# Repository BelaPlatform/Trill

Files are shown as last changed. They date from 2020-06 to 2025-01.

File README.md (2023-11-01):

# Trill: Touch Sensing for Makers

Trill sensors are designed to bring beautiful touch interaction to digital projects. Trill sensors are available now on the [Bela Shop](https://shop.bela.io/collections/trill) and via [Mouser Electronics](https://www.mouser.com/c/sensors/sensor-development-tools/?m=Bela).

## Trill libraries and examples

The Bela IDE comes pre-loaded with the [Trill library](https://github.com/BelaPlatform/Bela/tree/master/libraries/Trill) and [Trill examples](https://github.com/BelaPlatform/Bela/tree/master/examples/Trill).

For other platforms:

- [`Trill-Linux`](https://github.com/BelaPlatform/Trill-Linux) contains the Trill library and examples for Linux systems, such as Raspberry Pi

- [`Trill-Arduino`](https://github.com/BelaPlatform/Trill-Arduino) contains the Trill library and examples for Arduino, as well as Arduino-compatible systems such as Teensy. These also include examples of how to connect your Trill sensor to Processing to generate visuals.

## Trill hardware designs

This repo contains the editable PCB designs and manufacturing files for Trill sensors. You can download these schematic source and PCB design files and edit them yourself using [KiCad](https://www.kicad.org/).

### Source Files and Licenses

Trill hardware designs and this datasheet are available under a [Creative Commons Attribution-ShareAlike 4.0 International (CC BY-SA 4.0)](http://creativecommons.org/licenses/by-sa/4.0/) License, meaning they can be freely reused and remixed with attribution, provided modifications remain open source. Trill firmware is licensed under [GNU General Public License 3](https://www.gnu.org/licenses/gpl-3.0.html), meaning that you can freely use, remix, change and extend the code, but you are obligated to make the modified source code available alongside any binaries (flashed, or as files) that you release.

### Commercial Licensing

It's possible to use Trill design files and firmware for a commercial projects free of charge under [CC-BY-SA](http://creativecommons.org/licenses/by-sa/4.0/) (hardware) and [GPL](https://www.gnu.org/licenses/gpl-3.0.en.html) (firmware). Both licenses allow you to use these assets yourself under the license requirements, which include publicly releasing any changes you make to the designs under the same license.

If you want to use Trill design files but not provide attribution and/or not release your source code – for example, because you want to create something to sell using these files but don't want to make your source files public – this is still possible, but requires a commercial license. Augmented Instruments Ltd. can provide you with a commercial license that fits your project and its scope. Get in touch at info@bela.io to discuss your product and the license that's right for you. More information may be found at https://learn.bela.io/products/products-overview/open-source-licenses/#using-trill-in-commercial-products

Please note: The above commercial licensing applies only to modifications to our provided firmware code and PCB designs. You can buy Trill sensors and use them in any commercial or personal project without any additional licensing costs.

## Trill name and logo 

Trill and Bela names and logos are copyright Augmented Instruments Ltd. Any  designs that you release or produce should **not** use the Trill name or logo and/or the Bela name and logo, whether modified or exact copies.

## Datasheet

This repo contains the Trill datasheet. There is one datasheet for all Trill sensors that includes technical diagrams and usage information. 

## Fritzing files

Fritzing parts are available for all Trill sensors, in the [Bela Fritzing repo](https://github.com/belaplatform/fritzing).

## Learn more

The Bela Knowledge Base contains great documentation on using Trill! Visit [learn.bela.io/trill](https://learn.bela.io/trill) for more information, as well as our Get Started Guide.

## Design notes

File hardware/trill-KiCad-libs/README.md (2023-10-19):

# TRILL KiCad Library

This repo contains shared symbols, footprints and 3D files for TRILL projects.
Add the path to your symbols, footprints and 3d directory

## Installation

If all files of the repository are kept in place, the KiCad projects should contain the relative paths to the libraries and should find them without configuration. Please don't move folders!

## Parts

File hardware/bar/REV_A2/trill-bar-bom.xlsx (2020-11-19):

Name | Quantity | Value | Package | Description | Mouser # | Digi-Key # | Datasheet / Notes
C1 | 1 | 0.1uF | “0402" | Capacitor ceramic 0402; standard bypass cap 5V+
C2 | 1 | 2.2nF | “0402" | Capacitor ceramic 0402; 5% | 81-GRM36X222J50
IC1 | 1 | CY8C20636A-24LTXI | 48-QFN, 7x7mm | IC Cypress SoC | 727-CY8C20636A24LTXI
J1 | 1 | Grove connector, vertical SMT | SMD | 4-pin 2mm vertical Grove connector (Seeed)
R1-R2 | 2 | 100 ohm | “0402" | Resistor 0603 (standard part)
R3-R4 | 2 | 47k ohm | “0402" | Resistor 0603 (standard part)
Total | 8

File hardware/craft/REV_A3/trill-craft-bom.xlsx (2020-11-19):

Name | Quantity | Value | Package | Description | Mouser # | Digi-Key # | Datasheet / Notes
C1 | 1 | 0.1uF | "0603" | Capacitor ceramic 0402; standard bypass cap 5V+
C2 | 1 | 2.2nF | "0603" | Capacitor ceramic 0402; 5% | 81-GRM36X222J50
IC1 | 1 | CY8C20636A-24LTXI | 48-QFN, 7x7mm | IC Cypress SoC | 727-CY8C20636A24LTXI
R1-R2 | 2 | 100 ohm | "0603" | Resistor 0603 (standard part)
R3-R4 | 2 | 47k ohm | "0603" | Resistor 0603 (standard part)
Total | 7

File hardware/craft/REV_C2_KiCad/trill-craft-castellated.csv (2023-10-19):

Source: | /home/mxa/Code/Bela/trill-private/hardware/craft/REV_C2_KiCad/trill-craft-castellated.kicad_sch
Date: | So 26 Feb 2023 22:26:50 CET
Tool: | Eeschema 6.0.10-86aedd382b~118~ubuntu22.10.1
Generator: | /usr/share/kicad/plugins/bom_csv_grouped_by_value.py
Component Count: | 8
Individual Components:
Item | Qty | Reference(s) | Value | LibPart | Footprint | Datasheet
 |  | C1 | 100nF | Device:C | Capacitor_SMD:C_0402_1005Metric | ~
 |  | C2 | 2n2 | Device:C | Capacitor_SMD:C_0402_1005Metric | ~
 |  | JP1 | Jumper_2x3_Open | TRILL:Jumper_2x3_Open | TRILL:SolderJumper-2x3_P1.3mm_Open_Pad1.0x1.5mm | ~
 |  | R1 | 100 | Device:R | Resistor_SMD:R_0402_1005Metric | ~
 |  | R2 | 100 | Device:R | Resistor_SMD:R_0402_1005Metric | ~
 |  | R3 | 47k | Device:R | Resistor_SMD:R_0402_1005Metric | ~
 |  | R4 | 47k | Device:R | Resistor_SMD:R_0402_1005Metric | ~
 |  | U1 | CY8C206X6A | TRILL:CY8C206X6A | Package_DFN_QFN:QFN-48-1EP_6x6mm_P0.4mm_EP4.6x4.6mm | https://www.infineon.com/dgdl/Infineon-CY8C20XX6A_S_1.8_V_Programmable_CapSense_Controller_with_SmartSense_Auto-tuning_1-33_Buttons_0-6_Sliders-DataSheet-v26_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
Collated Components:
Item | Qty | Reference(s) | Value | LibPart | Footprint | Datasheet
1 | 1 | C1 | 100nF | Device:C | Capacitor_SMD:C_0402_1005Metric | ~
2 | 1 | C2 | 2n2 | Device:C | Capacitor_SMD:C_0402_1005Metric | ~
3 | 1 | JP1 | Jumper_2x3_Open | TRILL:Jumper_2x3_Open | TRILL:SolderJumper-2x3_P1.3mm_Open_Pad1.0x1.5mm | ~
4 | 2 | R1, R2 | 100 | Device:R | Resistor_SMD:R_0402_1005Metric | ~
5 | 2 | R3, R4 | 47k | Device:R | Resistor_SMD:R_0402_1005Metric | ~
6 | 1 | U1 | CY8C206X6A | TRILL:CY8C206X6A | Package_DFN_QFN:QFN-48-1EP_6x6mm_P0.4mm_EP4.6x4.6mm | https://www.infineon.com/dgdl/Infineon-CY8C20XX6A_S_1.8_V_Programmable_CapSense_Controller_with_SmartSense_Auto-tuning_1-33_Buttons_0-6_Sliders-DataSheet-v26_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

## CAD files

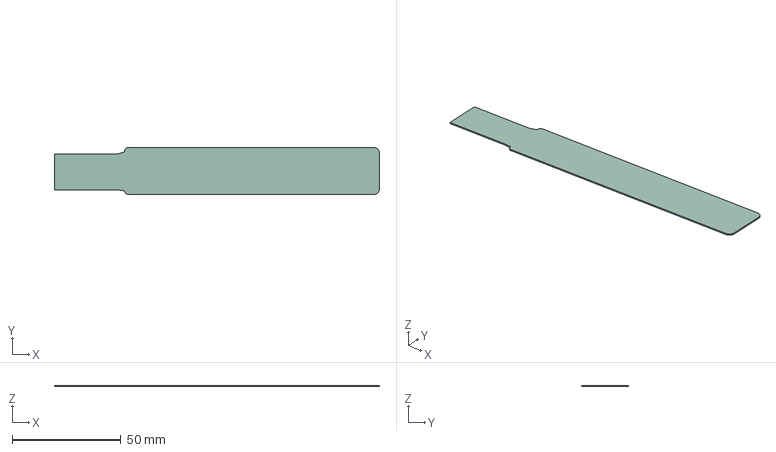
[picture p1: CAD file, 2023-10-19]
hardware/flex/trill-flex-slider/REV-C1-KiCad/trill-flex-slider.step
149.6 x 21.6 x 0.55 mm

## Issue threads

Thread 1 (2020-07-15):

Trill Square Firmware flashing question

jwktje, 2020-07-15:
Thanks very much first of all for open-sourcing all design files and code.
For a hobby project I'm trying to study the schematics and code to learn from it because I'm trying to build a prototype with capacitive touch.

I've already ordered a Trill Square to test with.
I was wondering however. If I was to integrate a design into my full PCB that integrates the CY8C20636A, how would I flash that IC?

The datasheet seems to mention something about the  CY3217-MiniProg1. Is that what I use to flash the sensor firmware or could I use something like an FTDI?

giuliomoro, 2020-07-23:
> The datasheet seems to mention something about the CY3217-MiniProg1.

The PSoC programmer that comes with it is one thing you could use.

You can also write your own embedded firmware and create a programming device yourself, and they provide a basic C library to do that. See these documents by Cypress for further details:
- "Host Sourced Serial Programming for CY8C20xx6A, CY8C20xx6AS, CY8C20xx6L, CY8C20xx7, CY8C20045
- CY8C20055" (AN59389) and "ISSP Programming Specification" (Document #: 001-57631)

fenicento, 2020-12-01:
I know it's not the best place to ask but I couldn't reach you personally, so feel free to remove this post: do you by any chance use HSSP with an Arduino, Teensy, or any other maker-friendly board? If so, would you mind sharing it? I'm having a hard time finding a programmer for CY8C20636A and can't really manage to write a firmware for a custom programmer.

Thanks

giuliomoro, 2020-12-02:
you don't need to write a programmer from scratch. The second resource mentioned above includes a zip archive with a C implementation of the protocol. I am not sure what platform it is for, but you can port it to your platform of choice by replacing the functions in `issp_driver_routines.c` so that they work on your platform.

Alternatively, some PSoC programmers seem to still be around there [somewhere](https://www.aliexpress.com/item/32381156184.html).

Closed 2020-12-02.

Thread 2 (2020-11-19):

Trill Craft R and C values

fenicento, 2020-11-19:
It is not specified what use and values the resistors and capacitors on boards have. I'll try to make a guess for the ones in the Trill Craft, but it would be nice to integrate these info in the repo.

R1 and R2: I2C pull-up resistors, 4.7kΩ
R3 and R4: I2C address pin pull down resistor, 4.7kΩ
C1: decoupling capacitor, 0.1µF
C2: Cmod capacitor for Cypress CSA sensing method ([described here](http://dlm.cypress.com.edgesuite.net/akdlm/old/design_resources/developer_kits/contents/cy3280_24x94_universal_capsense_controller_board_16.pdf)), 1nF

are these values correct?

giuliomoro, 2020-11-19:
sorry BOMs were missing. They are there now

Closed 2020-11-19.

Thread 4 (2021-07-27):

Trill square not completely flat

wjslager, 2021-07-27:
I have a trill square here that is not 100% flat. Not really a big issue but if one would want to mount it flush in a surface the edges could stand out.

https://user-images.githubusercontent.com/3001621/127160647-299aba64-3ae9-411e-b594-94e6d92a7a33.mp4

I think this can be fixed by having equal amounts of copper on each layer, it seems like the backside of the PCB has only traces and no plane.

apmcpherson, 2021-07-28:
This is a good point, but maybe not an easy fix: adding solid copper to the back could increase baseline capacitance of the sensors and ultimately lower the sensitivity of the readings. We will keep an eye on the assembly process to see what we can do to keep them as flat as possible. Since the boards are relatively thin and partly flexible, they could perhaps be secured to a rigid backplane using adhesive.

mxa, 2023-10-24:
Closing, since this is a  issue inherent of the properties of the PCB, (thin, large, 4-layer), can't be solved by designing it differently while keeping the same properties.

mxa, 2023-10-24:
Closing, since this is a  issue inherent of the properties of the PCB, (thin, large, 4-layer), can't be solved by designing it differently while keeping the same properties.

mxa, 2023-10-24:
Closing, since this is a  issue inherent of the properties of the PCB, (thin, large, 4-layer), can't be solved by designing it differently while keeping the same properties.

mxa, 2023-10-24:
Closing, since this is a  issue inherent of the properties of the PCB, (thin, large, 4-layer), can't be solved by designing it differently while keeping the same properties.

Closed 2023-10-24.

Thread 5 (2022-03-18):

Request: Trill Craft (as a component) KiCAD library

DocSunset, 2022-03-18:
It would be fantastic to have KiCAD symbols and footprints for integrating Trill Craft into schematics and PCBs, similar to the library files available for the other Trill devices.

mxa, 2023-10-26:
Say hi to a craft symbol, footprint and 3d model to use in your projects.

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

mxa, 2023-10-28:
The footprint still needs to be verified in the physical world, feedback welcome, especially on the size and shape of the smd pads.

Closed 2023-10-26.

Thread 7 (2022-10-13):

Spurious touches reported

stonehippo, 2022-10-13:
I've come across an issue with a couple my Trill boards (specifically a Bar and a Square, both acquired during the Kickstarter campaign). The sensors will report a touch that is not there after it has been running for a while. For example, on my Square, I am getting a horizontal touch at centroid location 1280. This seems to be consistent, and happens with both the Trill-Arduino firmware and a driver that I've written for CircuitPython.

I haven't looked at the firmware yet, but I'm going to take a read through to see how centroids are calculated. However, because this issue seems to appear on the sensor between different software implementations on different microcontrollers, I have to this it's the sensor itself having issues.

Is this something others have seen?

giuliomoro, 2022-10-14:
Things that can cause ghost touches are moisture (e.g.: a thin layer of water on the surface or edge of the sensor) or something changing with the surroundings of the sensor. Is it resting on a flat surface, taped or glued down, or is it in a precarious position balancing on the cable sticking out of the back? Also remember that a sensor calibration is done automatically when the sensor is initialised by the sofware, so for instance if you have one finger on the sensor while the program starts and then you remove it you may have unexpected readings: you are not supposed to touch the sensor when the program starts.

stonehippo, 2022-10-15:
It's definitely not a touch during calls to updateBaseline. I've got the Square mounted in the 3D printed base, but it was happening beforehand, so I suspect it might be something on the sensor. In the case of the Bar, I think it was maybe a spec of dust on the pins of the chip; removing it may have resolved the issue on that sensor.

I do note that resetting the chip fixes the issue for a while (presumably because of the baseline update) but then it comes back, especially after a multiple touch. I'm going to dump the baseline for a while and see if I can map what's happening.

I've ordered a few more Trills for a project, and my CircuitPython library is almost complete, so I'll be spending plenty of time with them.

giuliomoro, 2022-10-15:
Good that it got fixed on the BAR. For the SQUARE, it would be helpful to look at the RAW pad readings when the ghost touch happens.

mxa, 2023-10-24:
A good place to continue this conversation is the Bela forum https://forum.bela.io/t/trill
Please share screenshots of the baseline readings.

Closed 2023-10-24.

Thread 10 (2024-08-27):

Table 12 in the datasheet appears to be incorrect

george-norton, 2024-08-27:
I have a Trill Hex rev C2 and I believe the centroid data report structure is different from the datasheet. The datasheet includes this table:
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
But I believe my sensor is actually reporting:
```
uint16_t vertical_location[4];
uint16_t vertical_size[4];
uint16_t horizontal_location[4];
uint16_t horizontal_size[4];
```

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
george-norton, 2024-08-27:
Hello, sorry - I am not sure what is in that zip file, is it new firmware?

FYI, I am running a Linux system and have started work on a QMK (mechanical keyboard firmware) driver for the Hex trackpad, I have not installed or run any of the Bela development tools.

giuliomoro, 2024-08-27:
Nope that was spam

GoldenCaterpie, 2024-08-27:
> Hello, sorry - I am not sure what is in that zip file, is it new firmware?
>
> FYI, I am running a Linux system and have started work on a QMK (mechanical keyboard firmware) driver for the Hex trackpad, I have not installed or run any of the Bela development tools.

SRRY, THAT'S A VIRUS AND MY ACCOUNT HAS BEEN HIJACKED BY IT :(

giuliomoro, 2024-08-27:
> But I believe my sensor is actually reporting:

 You are right. Keep in mind those uint16_t are big endian so if you are trying to map a `struct` to that it may or may not work depending on your architecture.

george-norton, 2024-08-27:
Yes, I am handling the byte swapping. I have a proof of concept functional driver.

giuliomoro, 2024-08-27:
Great, you can also look at the [arduino](https://github.com/BelaPlatform/Trill-Arduino) and [linux](https://github.com/BelaPlatform/Trill-Linux) libraries for any further doubts

george-norton, 2024-08-27:
This ticket is probably the wrong place, so please let me know if you want to move elsewhere. But the documentation states that the 2D sensors only support "pseudo multitouch" without providing any real details. I am imagining that the axes are being treated independently and it becomes difficult to track which x and y report are a pair? I can work with a single touch + contact count for emulating a mouse, but I am also working on some USB HID digitiser stuff with Azoteq and MaxTouch sensors. It would be great if I could somehow reliably track 2 or 3 fingers.

giuliomoro, 2024-08-27:
The correct memory map has
touch N location at offset 4 + N:N+1
touch N size at offset 4 + 2*numTouches + N:N+1
for 2-axis:
horizontal touch N location at offset 4 + 4*numTouches + N:N+1
horizontal touch N size at offset 4 + 6*numTouches + N:N+1

numTouches = 5 for 1-axis and
numTouches = 4 for 2-axis

Not sure how to best represent this in a a table.

giuliomoro, 2024-10-31:
Should look something like this I think
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

giuliomoro, 2024-10-31:
@clwe can you double check this diagram https://github.com/BelaPlatform/Trill/issues/10#issuecomment-2449711737 to make sure I didn't do anything wrong before Max translates it into Latex?

clwe, 2024-10-31:
OMG indexing hell!
You guessed it - there is a small error. The initial offset (4) to the formulas for indexing into the offsets was missing.
Maybe we could make it more explicit and show the array layout for the two variants as below?
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
The mapping with indexing formulas had a slight error as well. Lets take a small `n` for the running index and the big `N` for the maximum number of touches per device.

`N = 5` for 1-axis devices
`N = 4` for 2-axis devices

If touch number `n`  is `[0 ... N-1]` then the offsets for the fields corresponding to touch `n` in the array are:

`location = 4 + 2*n:2*n+1`
`size = 4 + 2*N + 2*n:2*n+1`
`horizontal location = 4 + 4*N + 2*n:2*n+1` (2-axis only)
`horizontal size = 4 + 6*N + 2*n:2*n+1` (2-axis only)

clwe, 2024-10-31:
@mxa here is a .csv:
[trill datasheet array mapping.csv](https://github.com/user-attachments/files/17590456/trill.datasheet.array.mapping.csv)

giuliomoro, 2024-10-31:
> The initial offset (4) to the formulas for indexing into the offsets was missing.

right, missing the 4 + then?

> Maybe we could make it more explicit and show the array layout for the two variants as below?

Maybe ... or maybe showing the formula makes it easier to translate into code?

mxa, 2024-11-01:
Revised table:

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

What should be changed in the text?

giuliomoro, 2024-11-01:
Editing needs to encompass the paragraph that starts at the beginning of 7.7.1:

The data in the Payload region represents the touch location and size for each of the touches that the device can detect. The location and size of each touch are each represented by a 2-byte word. Each word represents a 16-bit unsigned integer in Big Endian format. Touch location and size values are stored in a buffer of contiguous memory, starting from the beginning of the Payload region. For each sensing axis, location data for all touches is presented first, followed by size data. Devices with two axes of sensing (Trill Square, Trill Hex) store vertical touches first, followed by horizontal touches. The readings of the two exposed pads on Trill Ring are stored after the touch values as a 16-bit unsigned integers in Big Endian format.
The memory offset for the start of the location data for a given touch n on a given sensing axis is p + 2n; the memory offset for the start of the size data for a given touch n is p + 2N + 2n, where N is the total number of touches on the sensing axis. The offset p is 4 (the beginning of the Payload region) for 1-axis devices or for the first axis of sensing of 2-axis devices, while it is 4 + 2N for the second axis of sensing of 2-axis devices. Tables 12 and 13 detail the memory map of the Payload region for 1-axis and 2-axis devices, respectively.
The size of valid data (in bytes) in the Payload memory region for a sensor which provides a total of N touches across its axes and E extra pads is M = 4N + 2E. The host processor should read M bytes starting at offset 4 to retrieve the full touch data. The number of available touches and the corresponding data size for each sensor type in Centroid mode is shown in Table 14 . <<<< correct number?

giuliomoro, 2024-11-01:
^^^ worth reviewing that what I wrote matches the corrected diagrams :-)

giuliomoro, 2024-11-01:
also I think the captions should say `when _a_ {1,2}-axis sensor` (i.e.: add the "a")

giuliomoro, 2024-11-01:
Could be yes. Also, don't use "Horz", use "horizontal" or "horiz" if you need to abbreviate

clwe, 2024-11-01:
No need to parametrize a start point. It's taken into account. For example, to get the first horizontal touch position, you choose N=4 and n=0. So the offset is '4 + 4*4+ 0:1 = 20:21'.

Closed 2024-11-01.

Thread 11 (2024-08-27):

explain pseudo-multitouch in the datasheet

giuliomoro, 2024-08-27:
@george-norton write

> documentation states that the 2D sensors only support "pseudo multitouch" without providing any real details. I am imagining that the axes are being treated independently and it becomes difficult to track which x and y report are a pair? I can work with a single touch + contact count for emulating a mouse, but I am also working on some USB HID digitiser stuff with Azoteq and MaxTouch sensors. It would be great if I could somehow reliably track 2 or 3 fingers.

What we mean by pseudo-multitouch here is that there are 15 capacitive channels on each axis. What you get is a list of the touches on the horizontal axis and a list of touches on the vertical axis. If you have two touches, you will not know which vertical touch corresponds to which horizontal touch. Also, if you have multiple touches aligned on the same vertical axis they will look like a single touch on the horizontal axis.

Worth adding this to the datasheet

mxa, 2024-11-01:
Proposed new table footnote 1, getting rid of the term "pseudo-multi-touch" entirely:

Trill 2-axis pads (Trill Square and Trill Hex) are not multi-touch sensors. While they are able to detect that more than one finger is touching the pad, they are unable to determine the exact locations of the touch points unambiguously.
This is because these X/Y sensors feature a square matrix configuration of pads, with the 30 channels of capacitive sensing distributed between two axes (15 channels per axis). A single touch results in the return of one pair of X/Y coordinates, which are accurate. However, with multiple touches present, Trill will register all touches and return them as two lists, one list for touches on the X axis and the other list for touches on the Y axis. Unfortunately, there is no way to accurately pair these X and Y values to produce accurate touch locations.

Closed 2024-11-01.

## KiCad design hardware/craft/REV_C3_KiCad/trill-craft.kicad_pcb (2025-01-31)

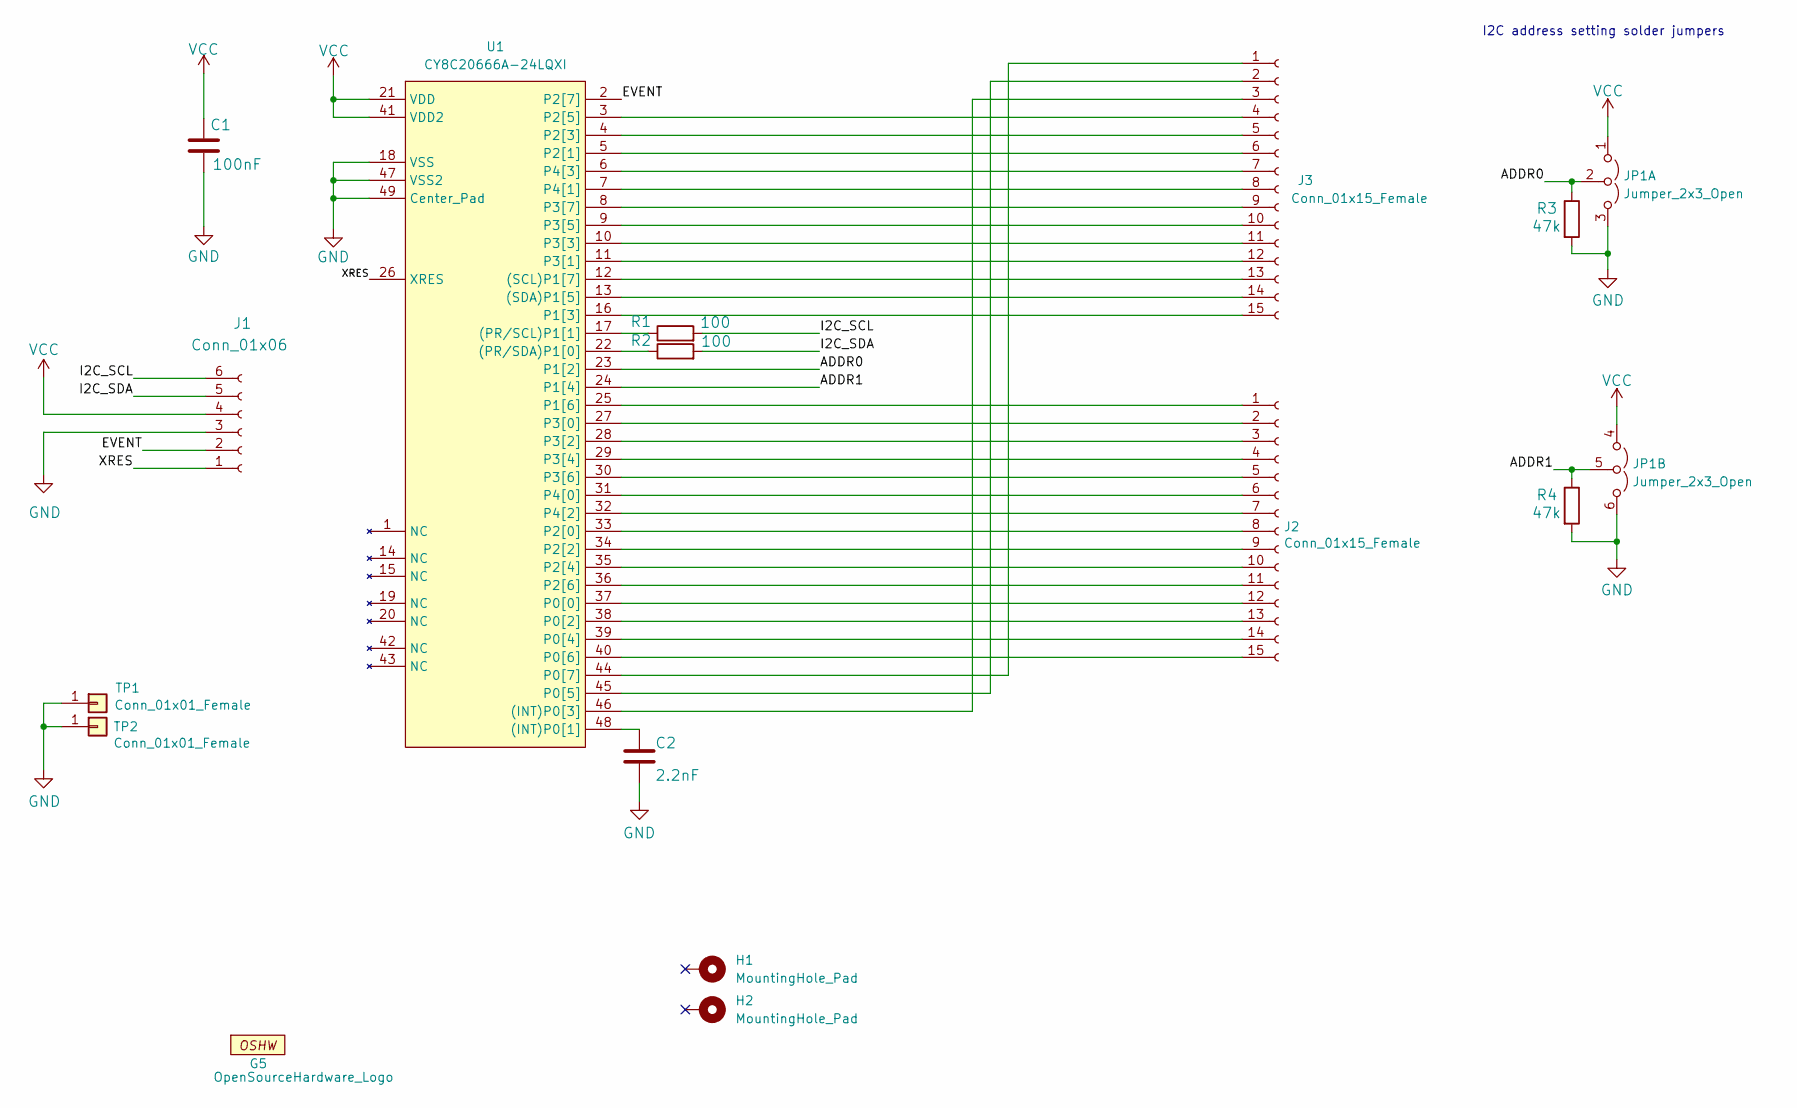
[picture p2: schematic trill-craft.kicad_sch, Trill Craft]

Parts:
C1: 100nF; C_0402_1005Metric
C2: 2.2nF; C_0402_1005Metric
G5: OpenSourceHardware_Logo
H1, H2: MountingHole_Pad; MountingHole_3.2mm_M3_ISO14580_Pad
J1: Conn_01x06; trill_craft_1X6_2.54mm_castelated_round
J2, J3: Conn_01x15_Female; trill_craft_1x15_2.54mm_castellated_round
JP1: Jumper_2x3_Open; SolderJumper-2x3_P1.3mm_Open_Pad1.0x1.5mm
R1, R2: 100; R_0402_1005Metric
R3, R4: 47k; R_0402_1005Metric
TP1, TP2: Conn_01x01_Female; trill_craft_circular_pad_smd
U1: CY8C20666A-24LQXI; QFN-48-1EP_6x6mm_P0.4mm_EP4.6x4.6mm

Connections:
/ADDR0: JP1.2 (C), R3.1, U1.23 (P1[2])
/ADDR1: JP1.5 (A), R4.1, U1.24 (P1[4])
/EVENT: J1.2, U1.2 (P2[7])
/I2C_SCL: J1.6, R1.2
/I2C_SDA: J1.5, R2.2
/XRES: J1.1, U1.26 (XRES)
GND: C1.1, C2.2, J1.3, JP1.3 (B), JP1.6 (B), R3.2, R4.2, TP1.1, TP2.1, U1.18 (VSS), U1.47 (VSS2), U1.49 (Center_Pad)
unnamed: J2.1, U1.25 (P1[6])
unnamed: J2.2, U1.27 (P3[0])
unnamed: J2.3, U1.28 (P3[2])
unnamed: J2.4, U1.29 (P3[4])
unnamed: J2.5, U1.30 (P3[6])
unnamed: J2.6, U1.31 (P4[0])
unnamed: J2.7, U1.32 (P4[2])
unnamed: J2.8, U1.33 (P2[0])
unnamed: J2.9, U1.34 (P2[2])
unnamed: J2.10, U1.35 (P2[4])
unnamed: J2.11, U1.36 (P2[6])
unnamed: J2.12, U1.37 (P0[0])
unnamed: J2.13, U1.38 (P0[2])
unnamed: J2.14, U1.39 (P0[4])
unnamed: J2.15, U1.40 (P0[6])
unnamed: J3.1, U1.44 (P0[7])
unnamed: J3.2, U1.45 (P0[5])
unnamed: J3.3, U1.46 ((INT)P0[3])
unnamed: J3.4, U1.3 (P2[5])
unnamed: J3.5, U1.4 (P2[3])
unnamed: J3.6, U1.5 (P2[1])
unnamed: J3.7, U1.6 (P4[3])
unnamed: J3.8, U1.7 (P4[1])
unnamed: J3.9, U1.8 (P3[7])
unnamed: J3.10, U1.9 (P3[5])
unnamed: J3.11, U1.10 (P3[3])
unnamed: J3.12, U1.11 (P3[1])
unnamed: J3.13, U1.12 ((SCL)P1[7])
unnamed: J3.14, U1.13 ((SDA)P1[5])
unnamed: J3.15, U1.16 (P1[3])
unnamed: C2.1, U1.48 ((INT)P0[1])
unnamed: R1.1, U1.17 ((PR/SCL)P1[1])
unnamed: R2.1, U1.22 ((PR/SDA)P1[0])
VCC: C1.2, J1.4, JP1.1 (A), JP1.4 (A), U1.21 (VDD), U1.41 (VDD2)

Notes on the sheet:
I2C address setting solder jumpers

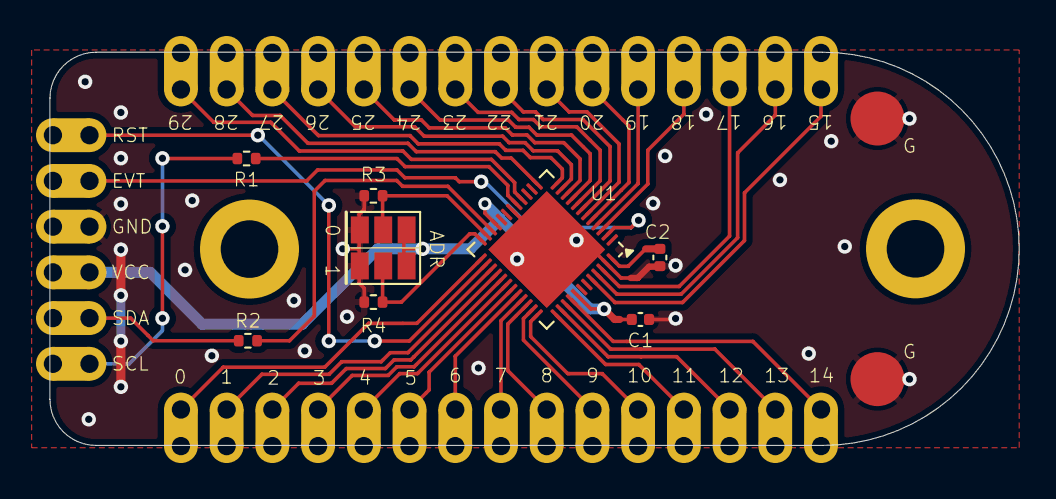
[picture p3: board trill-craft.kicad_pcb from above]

Board: 2 copper layers, 53.8 x 21.8 mm, 16 parts (1 on the bottom side), 41 nets.

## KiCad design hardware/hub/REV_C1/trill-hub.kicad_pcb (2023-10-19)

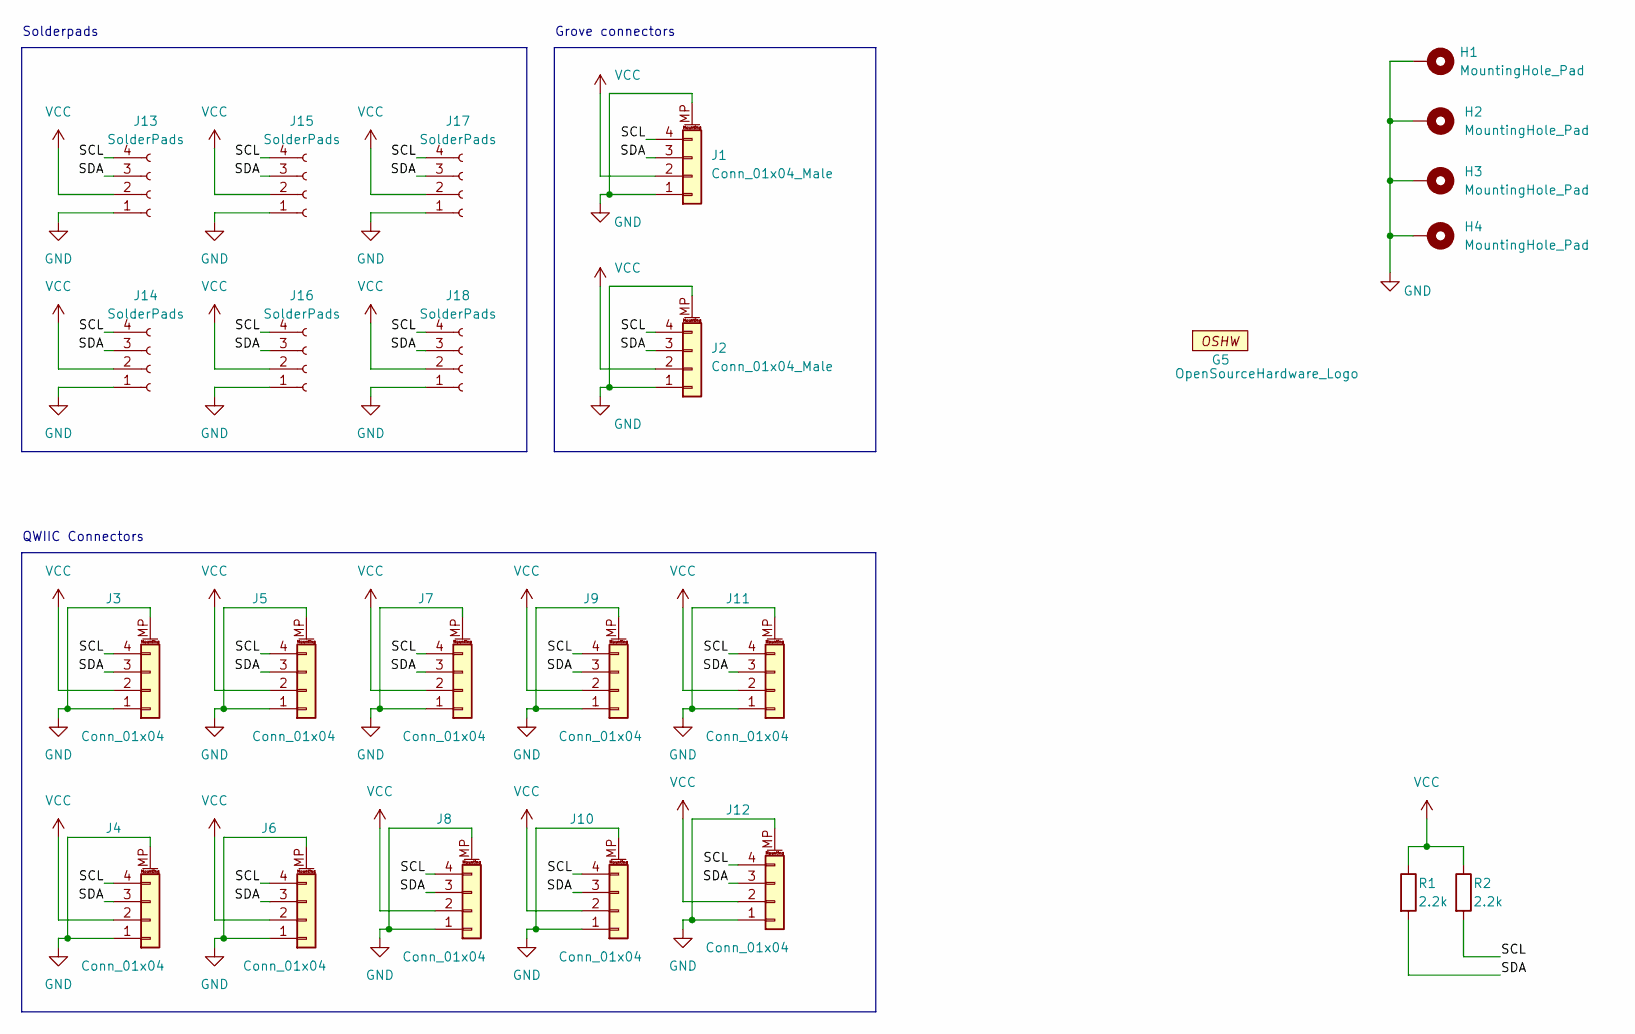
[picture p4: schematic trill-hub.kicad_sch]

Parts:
G5: OpenSourceHardware_Logo
H1, H2, H3, H4: MountingHole_Pad; MountingHole_3.2mm_M3_ISO14580_Pad
J1, J2: Conn_01x04_Male; JST_PH_B4B-PH-SM4-TB_1x04-1MP_P2.00mm_Vertical
J3, J4, J5, J6, J7, J8, J9, J10, J11, J12: Conn_01x04; qwiic_vertical_SMD
J13, J14, J15, J16, J17, J18: SolderPads; Connector_1x04_LongPads
R1, R2: 2.2k; R_0402_1005Metric

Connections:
/SCL: J1.4, J2.4, J3.4, J4.4, J5.4, J6.4, J7.4, J8.4, J9.4, J10.4, J11.4, J12.4, J13.4, J14.4, J15.4, J16.4, J17.4, J18.4, R2.2
/SDA: J1.3, J2.3, J3.3, J4.3, J5.3, J6.3, J7.3, J8.3, J9.3, J10.3, J11.3, J12.3, J13.3, J14.3, J15.3, J16.3, J17.3, J18.3, R1.2
GND: H1.1, H2.1, H3.1, H4.1, J1.1, J1.MP (MountPin), J2.1, J2.MP (MountPin), J3.1, J3.MP (MountPin), J4.1, J4.MP (MountPin), J5.1, J5.MP (MountPin), J6.1, J6.MP (MountPin), J7.1, J7.MP (MountPin), J8.1, J8.MP (MountPin), J9.1, J9.MP (MountPin), J10.1, J10.MP (MountPin), J11.1, J11.MP (MountPin), J12.1, J12.MP (MountPin), J13.1, J14.1, J15.1, J16.1, J17.1, J18.1
VCC: J1.2, J2.2, J3.2, J4.2, J5.2, J6.2, J7.2, J8.2, J9.2, J10.2, J11.2, J12.2, J13.2, J14.2, J15.2, J16.2, J17.2, J18.2, R1.1, R2.1

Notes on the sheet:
Solderpads
QWIIC Connectors
Grove connectors

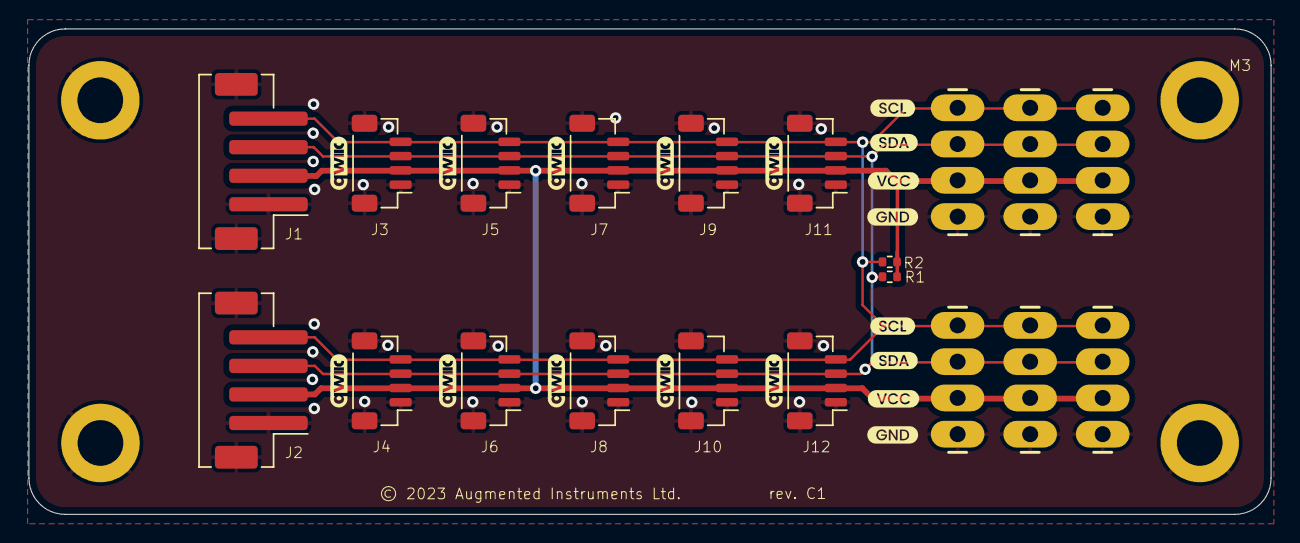
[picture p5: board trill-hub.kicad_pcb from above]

Board: 2 copper layers, 87.0 x 34.0 mm, 25 parts (1 on the bottom side), 4 nets.

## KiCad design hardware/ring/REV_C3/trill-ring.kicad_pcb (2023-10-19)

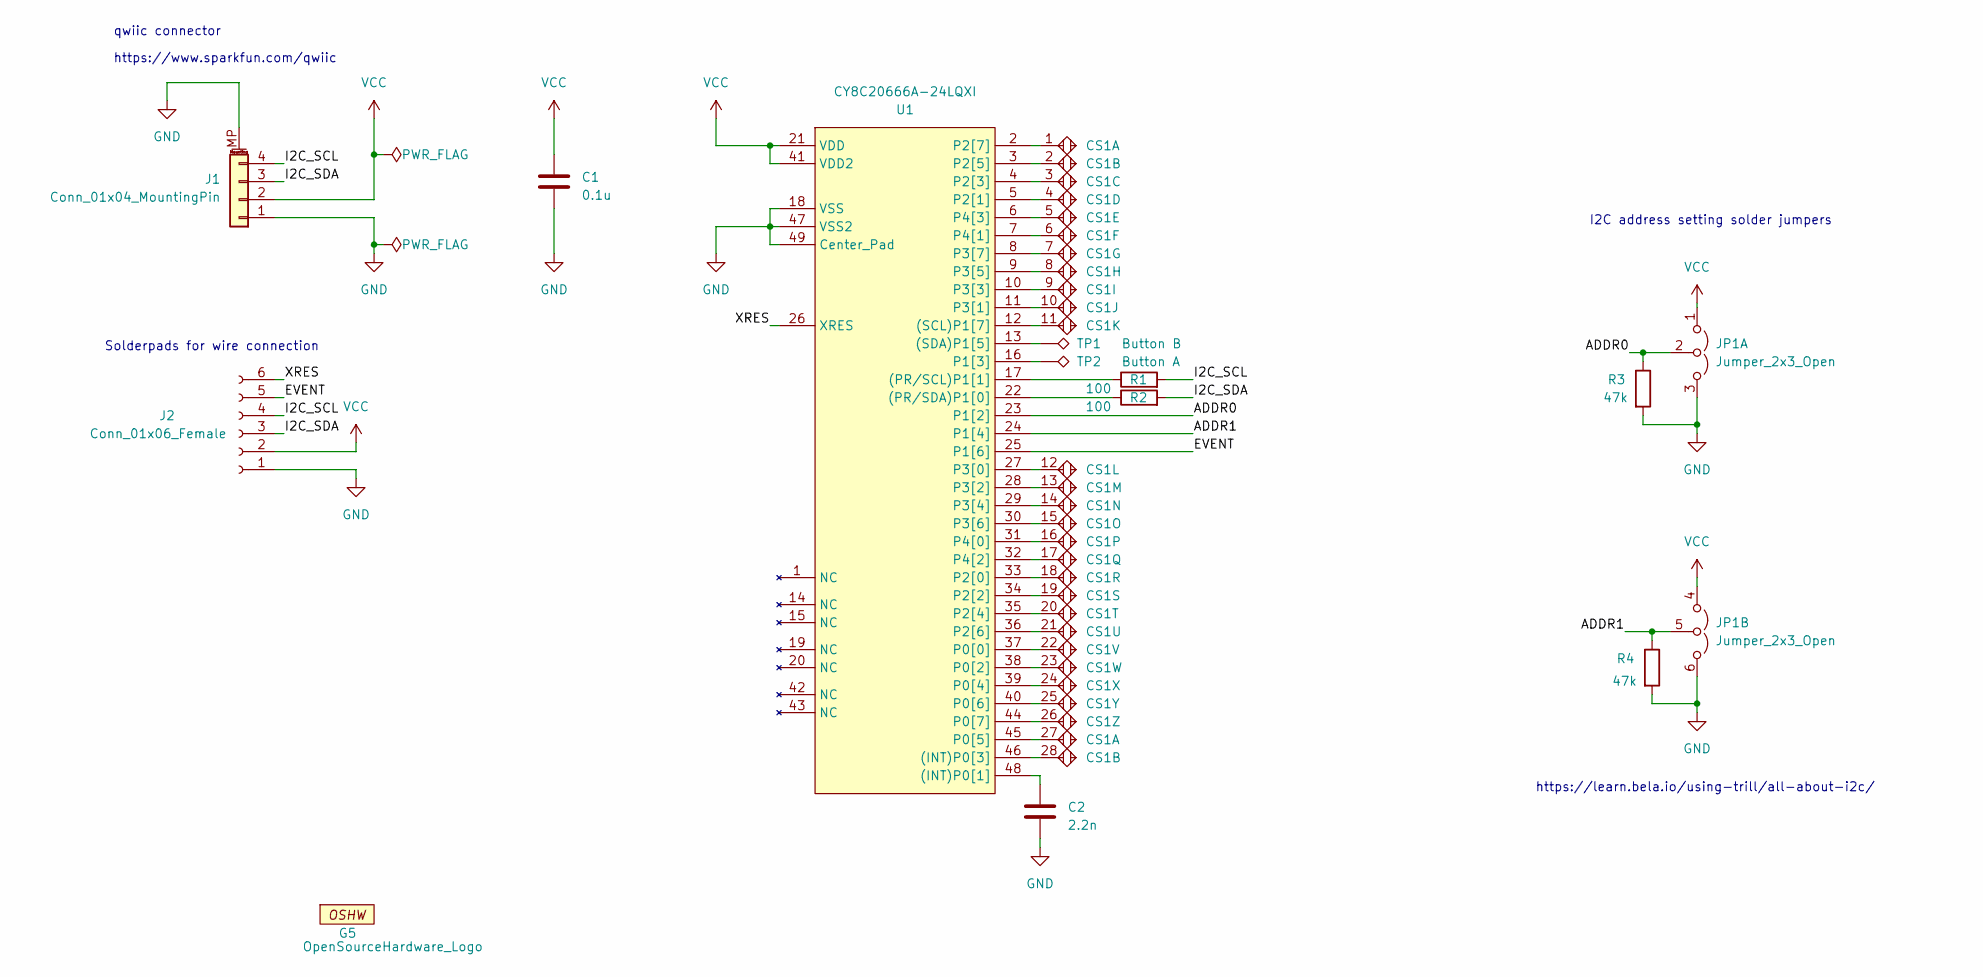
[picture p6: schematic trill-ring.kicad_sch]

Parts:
C1: 0.1u; C_0402_1005Metric
C2: 2.2n; C_0402_1005Metric
CS1: TRILL_RING-28_CapSense; TRILL_RING_CapSense
G5: OpenSourceHardware_Logo
J1: Conn_01x04_MountingPin; qwiic_horizontal_SMD
J2: Conn_01x06_Female; I2C+EVT_RST_Wire_connector_SMD
JP1: Jumper_2x3_Open; SolderJumper-2x3_P1.3mm_Open_Pad1.0x1.5mm
R1, R2: 100; R_0402_1005Metric
R3, R4: 47k; R_0402_1005Metric
TP1: Button B; TestPoint_Pad_D2.0mm
TP2: Button A; TestPoint_Pad_D2.0mm
U1: CY8C20666A-24LQXI; QFN-48-1EP_6x6mm_P0.4mm_EP4.6x4.6mm

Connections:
/ADDR0: JP1.2 (C), R3.1, U1.23 (P1[2])
/ADDR1: JP1.5 (A), R4.1, U1.24 (P1[4])
/EVENT: J2.5, U1.25 (P1[6])
/I2C_SCL: J1.4, J2.4, R1.2
/I2C_SDA: J1.3, J2.3, R2.2
/XRES: J2.6, U1.26 (XRES)
GND: C1.2, C2.2, J1.1, J1.MP (MountPin), J2.1, JP1.3 (B), JP1.6 (B), R3.2, R4.2, U1.18 (VSS), U1.47 (VSS2), U1.49 (Center_Pad)
unnamed: C2.1, U1.48 ((INT)P0[1])
unnamed: CS1.28, U1.46 ((INT)P0[3])
unnamed: R1.1, U1.17 ((PR/SCL)P1[1])
unnamed: R2.1, U1.22 ((PR/SDA)P1[0])
unnamed: CS1.11, U1.12 ((SCL)P1[7])
unnamed: TP1.1, U1.13 ((SDA)P1[5])
unnamed: CS1.22, U1.37 (P0[0])
unnamed: CS1.23, U1.38 (P0[2])
unnamed: CS1.24, U1.39 (P0[4])
unnamed: CS1.27, U1.45 (P0[5])
unnamed: CS1.25, U1.40 (P0[6])
unnamed: CS1.26, U1.44 (P0[7])
unnamed: TP2.1, U1.16 (P1[3])
unnamed: CS1.18, U1.33 (P2[0])
unnamed: CS1.4, U1.5 (P2[1])
unnamed: CS1.19, U1.34 (P2[2])
unnamed: CS1.3, U1.4 (P2[3])
unnamed: CS1.20, U1.35 (P2[4])
unnamed: CS1.2, U1.3 (P2[5])
unnamed: CS1.21, U1.36 (P2[6])
unnamed: CS1.1, U1.2 (P2[7])
unnamed: CS1.12, U1.27 (P3[0])
unnamed: CS1.10, U1.11 (P3[1])
unnamed: CS1.13, U1.28 (P3[2])
unnamed: CS1.9, U1.10 (P3[3])
unnamed: CS1.14, U1.29 (P3[4])
unnamed: CS1.8, U1.9 (P3[5])
unnamed: CS1.15, U1.30 (P3[6])
unnamed: CS1.7, U1.8 (P3[7])
unnamed: CS1.16, U1.31 (P4[0])
unnamed: CS1.6, U1.7 (P4[1])
unnamed: CS1.17, U1.32 (P4[2])
unnamed: CS1.5, U1.6 (P4[3])
VCC: C1.1, J1.2, J2.2, JP1.1 (A), JP1.4 (A), U1.21 (VDD), U1.41 (VDD2)

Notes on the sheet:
I2C address setting solder jumpers
qwiic connector
Solderpads for wire connection
https://learn.bela.io/using-trill/all-about-i2c/
https://www.sparkfun.com/qwiic

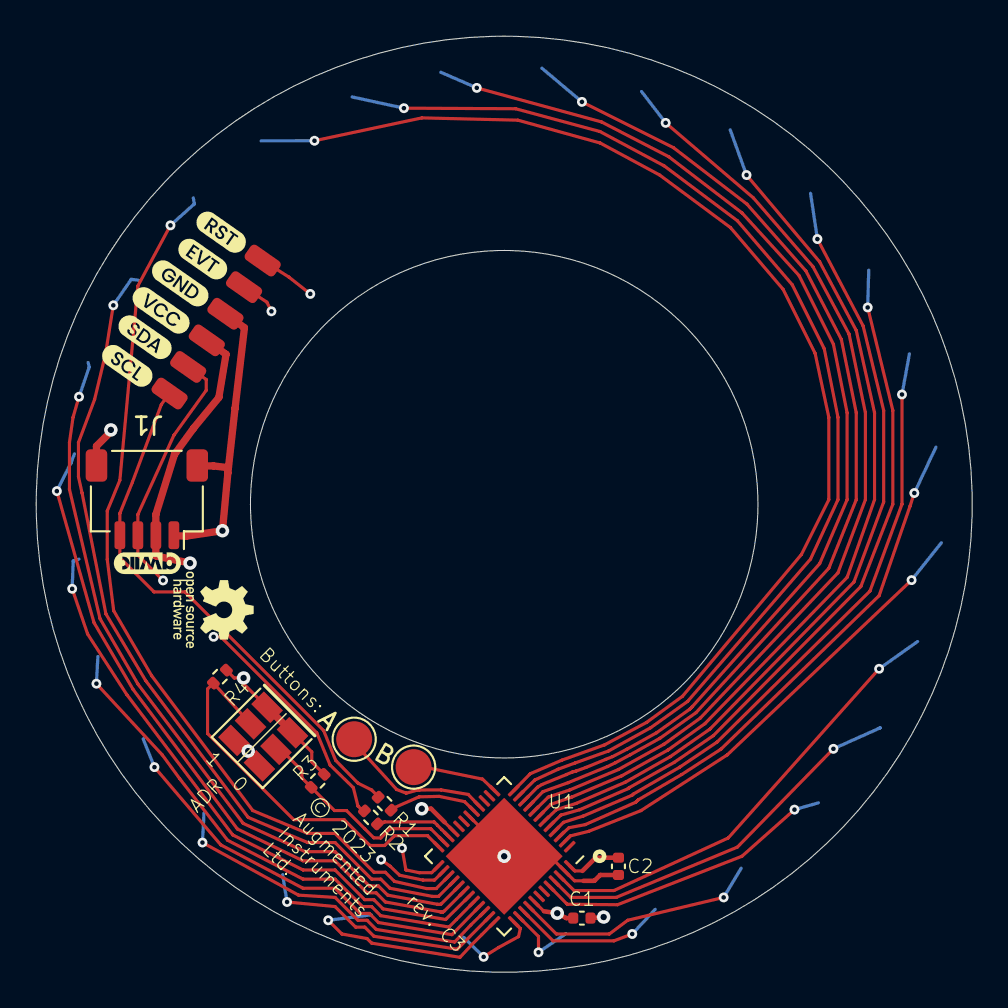
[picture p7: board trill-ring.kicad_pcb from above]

Board: 4 copper layers, 52.0 x 52.0 mm, 14 parts (0 on the bottom side), 41 nets.

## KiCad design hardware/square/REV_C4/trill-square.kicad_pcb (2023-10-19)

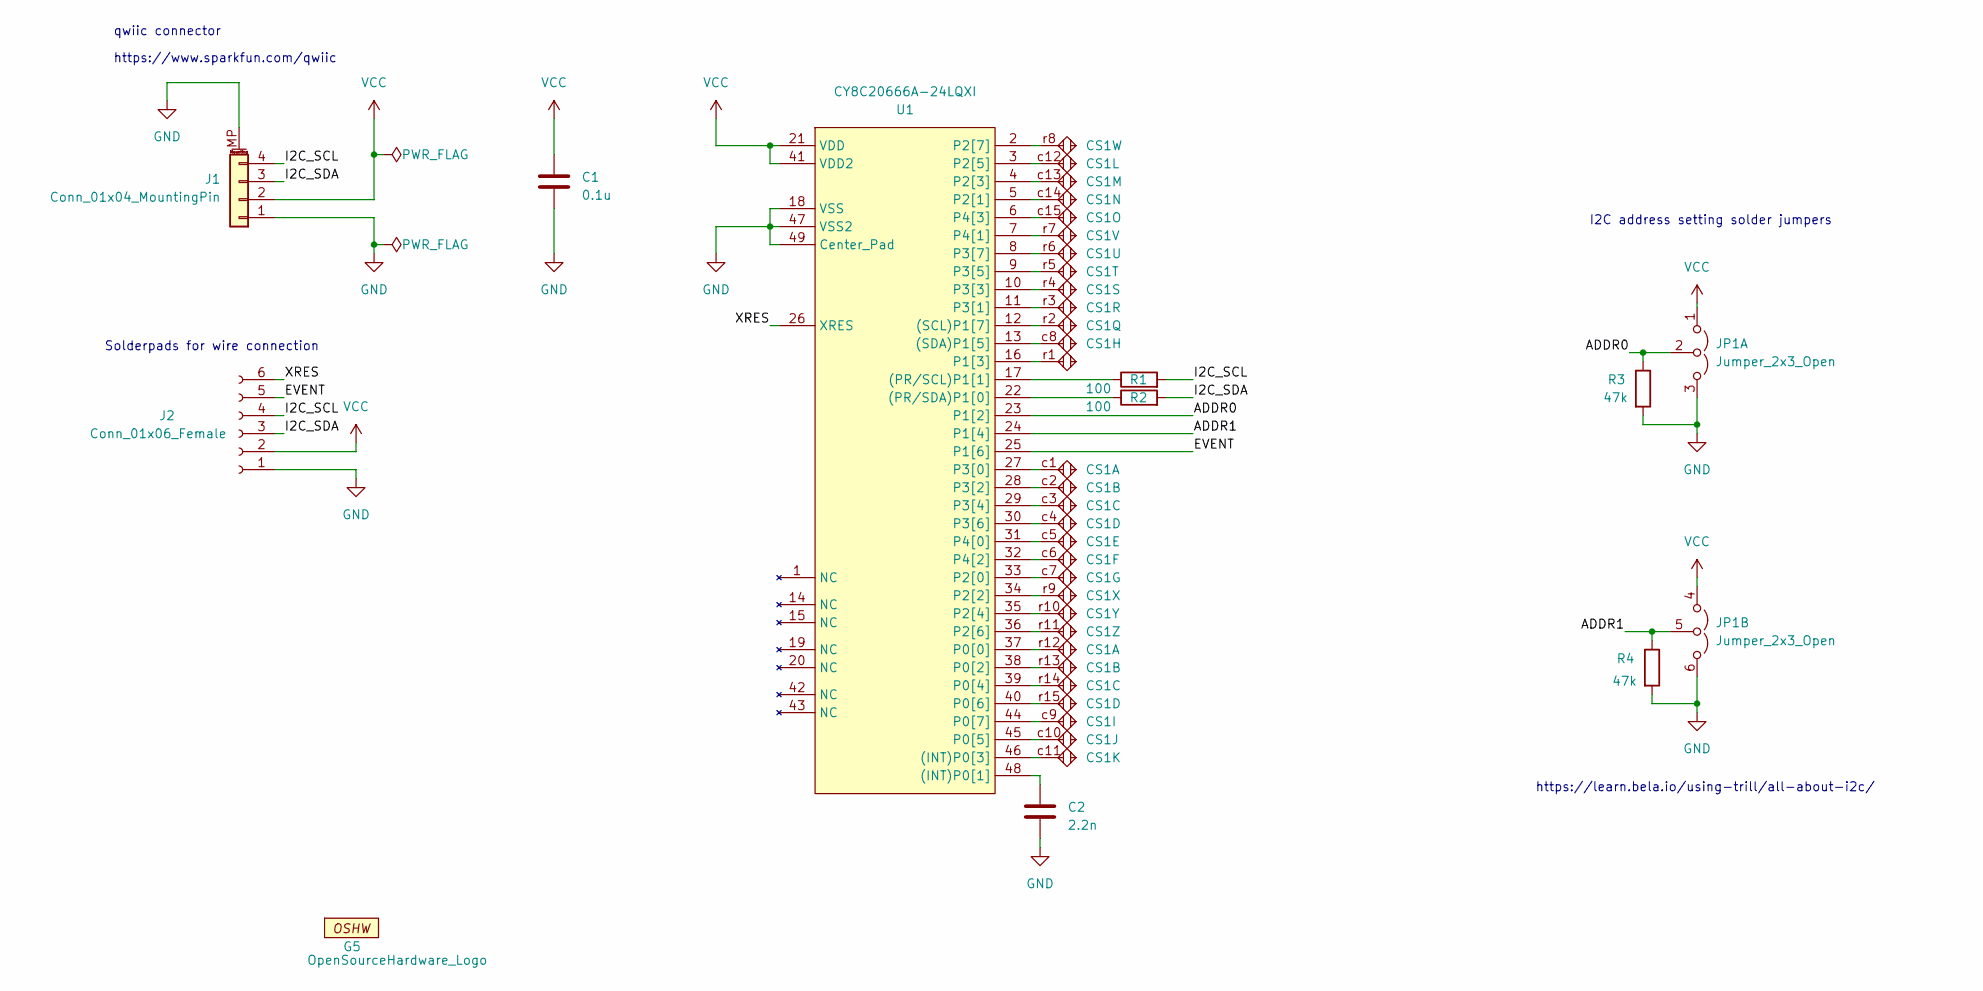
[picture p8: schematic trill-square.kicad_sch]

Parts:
C1: 0.1u; C_0402_1005Metric
C2: 2.2n; C_0402_1005Metric
CS1: CapSensePad; TRILL_SQUARE_CapSense
G5: OpenSourceHardware_Logo
J1: Conn_01x04_MountingPin; qwiic_horizontal_SMD
J2: Conn_01x06_Female; I2C+EVT_RST_Wire_connector_SMD
JP1: Jumper_2x3_Open; SolderJumper-2x3_P1.3mm_Open_Pad1.0x1.5mm
R1, R2: 100; R_0402_1005Metric
R3, R4: 47k; R_0402_1005Metric
U1: CY8C20666A-24LQXI; QFN-48-1EP_6x6mm_P0.4mm_EP4.6x4.6mm

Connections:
/ADDR0: JP1.2 (C), R3.1, U1.23 (P1[2])
/ADDR1: JP1.5 (A), R4.1, U1.24 (P1[4])
/EVENT: J2.5, U1.25 (P1[6])
/I2C_SCL: J1.4, J2.4, R1.2
/I2C_SDA: J1.3, J2.3, R2.2
/XRES: J2.6, U1.26 (XRES)
GND: C1.2, C2.2, J1.1, J1.MP (MountPin), J2.1, JP1.3 (B), JP1.6 (B), R3.2, R4.2, U1.18 (VSS), U1.47 (VSS2), U1.49 (Center_Pad)
unnamed: C2.1, U1.48 ((INT)P0[1])
unnamed: CS1.c11, U1.46 ((INT)P0[3])
unnamed: R1.1, U1.17 ((PR/SCL)P1[1])
unnamed: R2.1, U1.22 ((PR/SDA)P1[0])
unnamed: CS1.r2, U1.12 ((SCL)P1[7])
unnamed: CS1.c8, U1.13 ((SDA)P1[5])
unnamed: CS1.r12, U1.37 (P0[0])
unnamed: CS1.r13, U1.38 (P0[2])
unnamed: CS1.r14, U1.39 (P0[4])
unnamed: CS1.c10, U1.45 (P0[5])
unnamed: CS1.r15, U1.40 (P0[6])
unnamed: CS1.c9, U1.44 (P0[7])
unnamed: CS1.r1, U1.16 (P1[3])
unnamed: CS1.c7, U1.33 (P2[0])
unnamed: CS1.c14, U1.5 (P2[1])
unnamed: CS1.r9, U1.34 (P2[2])
unnamed: CS1.c13, U1.4 (P2[3])
unnamed: CS1.r10, U1.35 (P2[4])
unnamed: CS1.c12, U1.3 (P2[5])
unnamed: CS1.r11, U1.36 (P2[6])
unnamed: CS1.r8, U1.2 (P2[7])
unnamed: CS1.c1, U1.27 (P3[0])
unnamed: CS1.r3, U1.11 (P3[1])
unnamed: CS1.c2, U1.28 (P3[2])
unnamed: CS1.r4, U1.10 (P3[3])
unnamed: CS1.c3, U1.29 (P3[4])
unnamed: CS1.r5, U1.9 (P3[5])
unnamed: CS1.c4, U1.30 (P3[6])
unnamed: CS1.r6, U1.8 (P3[7])
unnamed: CS1.c5, U1.31 (P4[0])
unnamed: CS1.r7, U1.7 (P4[1])
unnamed: CS1.c6, U1.32 (P4[2])
unnamed: CS1.c15, U1.6 (P4[3])
VCC: C1.1, J1.2, J2.2, JP1.1 (A), JP1.4 (A), U1.21 (VDD), U1.41 (VDD2)

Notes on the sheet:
Solderpads for wire connection
qwiic connector
https://www.sparkfun.com/qwiic
https://learn.bela.io/using-trill/all-about-i2c/
I2C address setting solder jumpers

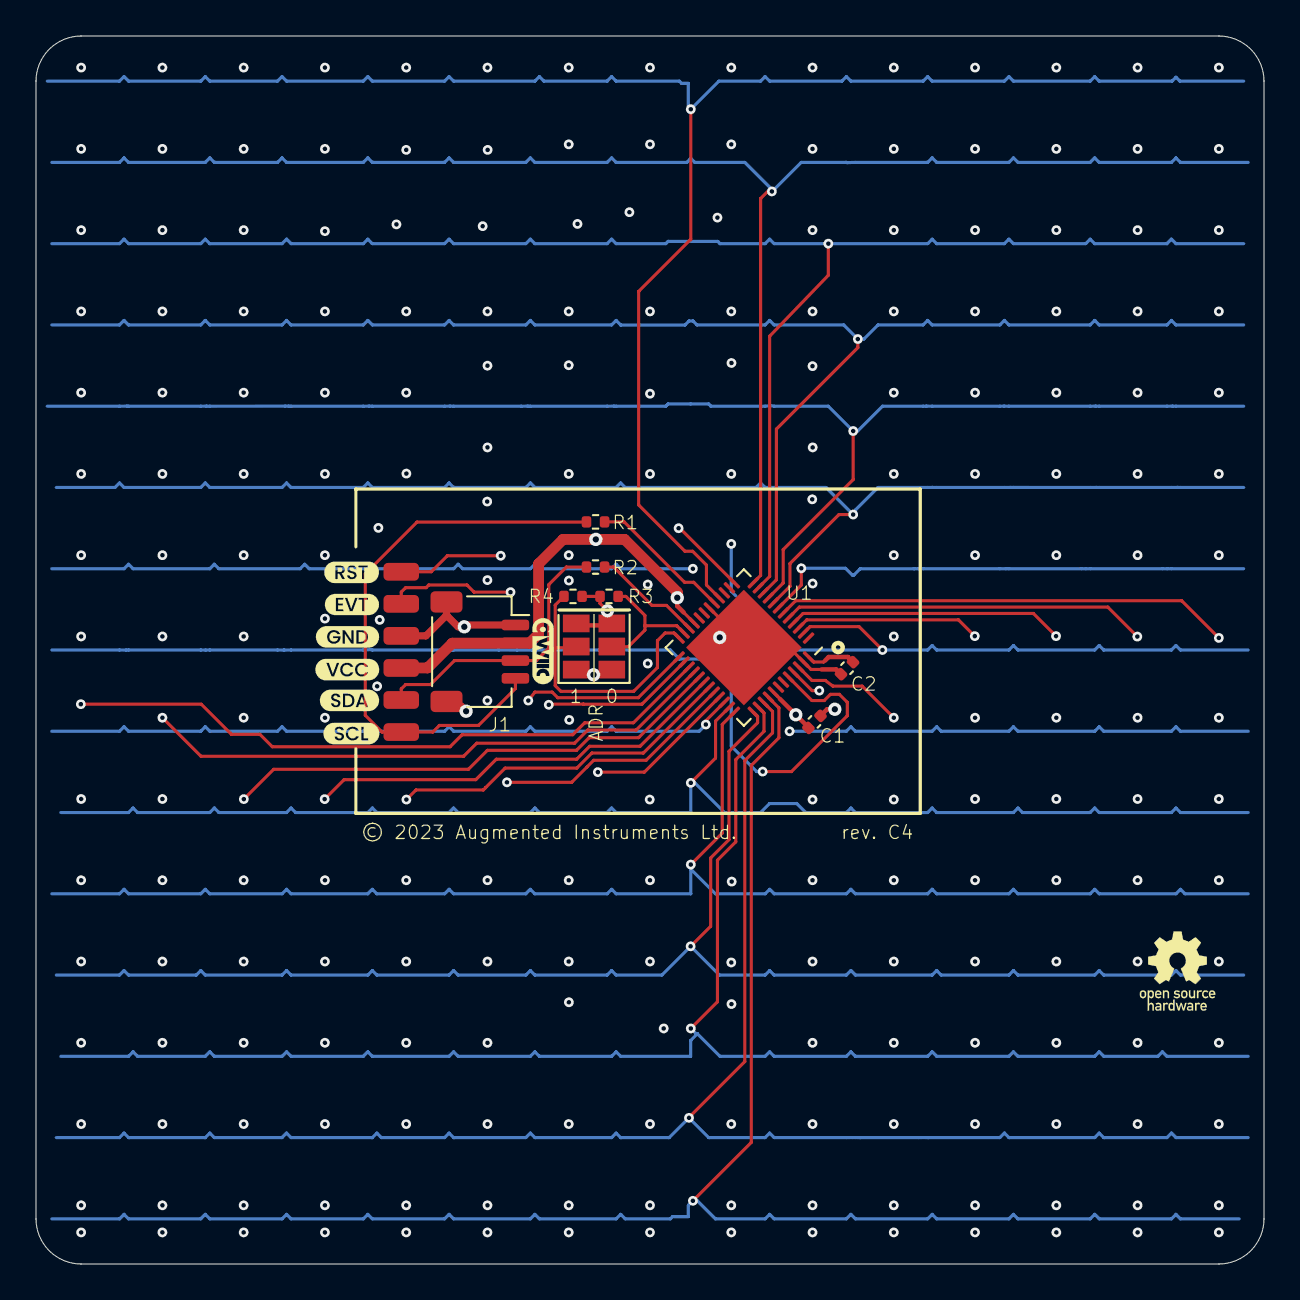
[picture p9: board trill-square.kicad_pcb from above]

Board: 4 copper layers, 69.1 x 69.1 mm, 12 parts (0 on the bottom side), 41 nets.

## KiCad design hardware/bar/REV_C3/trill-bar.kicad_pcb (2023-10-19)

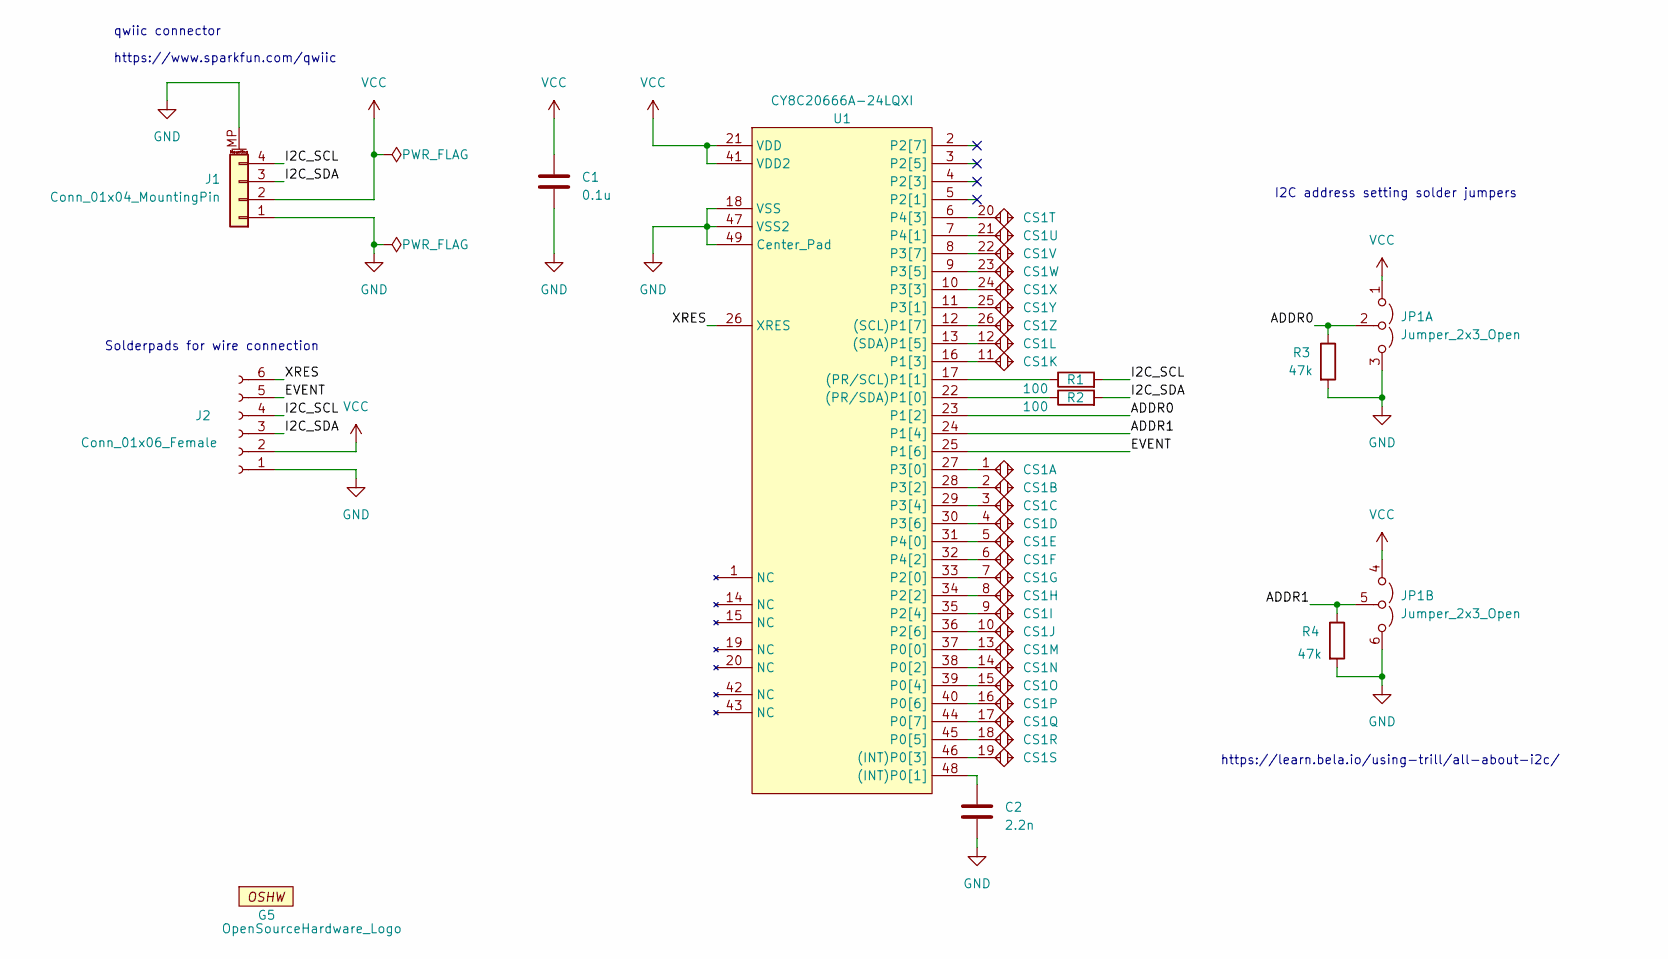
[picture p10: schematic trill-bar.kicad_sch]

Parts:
C1: 0.1u; C_0402_1005Metric
C2: 2.2n; C_0402_1005Metric
CS1: TRILL_BAR-26_CapSense; TRILL_BAR_CapSense
G5: OpenSourceHardware_Logo
J1: Conn_01x04_MountingPin; qwiic_horizontal_SMD
J2: Conn_01x06_Female; I2C+EVT_RST_Wire_connector_SMD
JP1: Jumper_2x3_Open; SolderJumper-2x3_P1.3mm_Open_Pad1.0x1.5mm
R1, R2: 100; R_0402_1005Metric
R3, R4: 47k; R_0402_1005Metric
U1: CY8C20666A-24LQXI; QFN-48-1EP_6x6mm_P0.4mm_EP4.6x4.6mm

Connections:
/ADDR0: JP1.2 (C), R3.1, U1.23 (P1[2])
/ADDR1: JP1.5 (A), R4.1, U1.24 (P1[4])
/EVENT: J2.5, U1.25 (P1[6])
/I2C_SCL: J1.4, J2.4, R1.2
/I2C_SDA: J1.3, J2.3, R2.2
/XRES: J2.6, U1.26 (XRES)
GND: C1.2, C2.2, J1.1, J1.MP (MountPin), J2.1, JP1.3 (B), JP1.6 (B), R3.2, R4.2, U1.18 (VSS), U1.47 (VSS2), U1.49 (Center_Pad)
unnamed: C2.1, U1.48 ((INT)P0[1])
unnamed: CS1.19, U1.46 ((INT)P0[3])
unnamed: R1.1, U1.17 ((PR/SCL)P1[1])
unnamed: R2.1, U1.22 ((PR/SDA)P1[0])
unnamed: CS1.26, U1.12 ((SCL)P1[7])
unnamed: CS1.12, U1.13 ((SDA)P1[5])
unnamed: CS1.13, U1.37 (P0[0])
unnamed: CS1.14, U1.38 (P0[2])
unnamed: CS1.15, U1.39 (P0[4])
unnamed: CS1.18, U1.45 (P0[5])
unnamed: CS1.16, U1.40 (P0[6])
unnamed: CS1.17, U1.44 (P0[7])
unnamed: CS1.11, U1.16 (P1[3])
unnamed: CS1.7, U1.33 (P2[0])
unnamed: CS1.8, U1.34 (P2[2])
unnamed: CS1.9, U1.35 (P2[4])
unnamed: CS1.10, U1.36 (P2[6])
unnamed: CS1.1, U1.27 (P3[0])
unnamed: CS1.25, U1.11 (P3[1])
unnamed: CS1.2, U1.28 (P3[2])
unnamed: CS1.24, U1.10 (P3[3])
unnamed: CS1.3, U1.29 (P3[4])
unnamed: CS1.23, U1.9 (P3[5])
unnamed: CS1.4, U1.30 (P3[6])
unnamed: CS1.22, U1.8 (P3[7])
unnamed: CS1.5, U1.31 (P4[0])
unnamed: CS1.21, U1.7 (P4[1])
unnamed: CS1.6, U1.32 (P4[2])
unnamed: CS1.20, U1.6 (P4[3])
VCC: C1.1, J1.2, J2.2, JP1.1 (A), JP1.4 (A), U1.21 (VDD), U1.41 (VDD2)

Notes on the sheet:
qwiic connector
I2C address setting solder jumpers
Solderpads for wire connection
https://learn.bela.io/using-trill/all-about-i2c/
https://www.sparkfun.com/qwiic

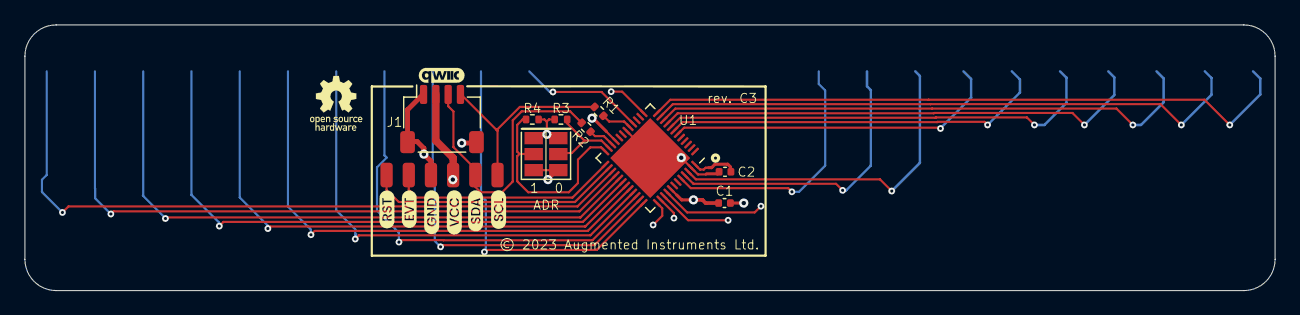
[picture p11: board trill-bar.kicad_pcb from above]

Board: 4 copper layers, 101.6 x 21.6 mm, 12 parts (0 on the bottom side), 37 nets.

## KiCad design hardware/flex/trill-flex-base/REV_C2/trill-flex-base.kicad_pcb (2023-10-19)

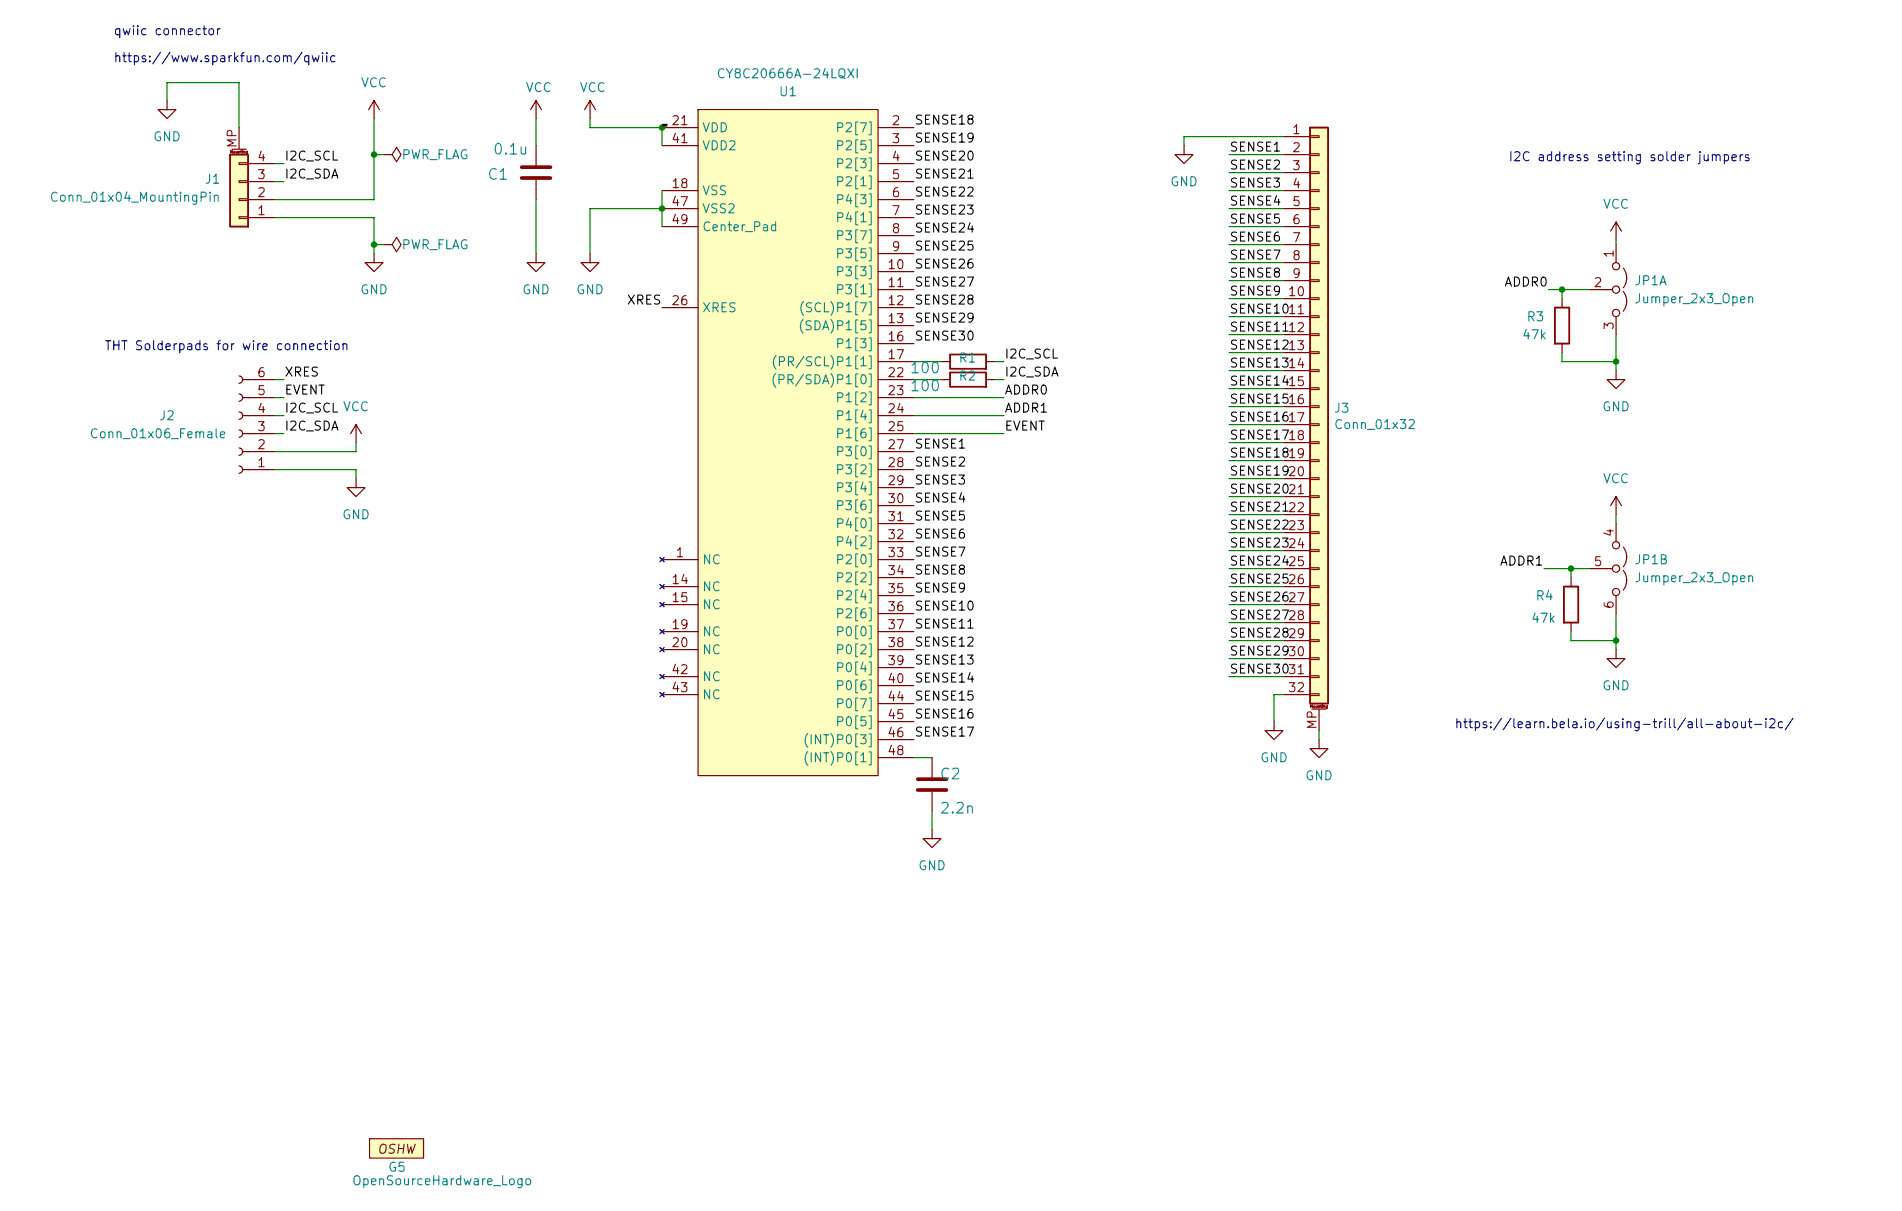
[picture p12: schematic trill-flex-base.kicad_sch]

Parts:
C1: 0.1u; C_0402_1005Metric
C2: 2.2n; C_0402_1005Metric
G5: OpenSourceHardware_Logo
J1: Conn_01x04_MountingPin; qwiic_horizontal_SMD
J2: Conn_01x06_Female; I2C+EVT_RST_Wire_connector_THT
J3: Conn_01x32; Hirose_FH12-32S-0.5SH_1x32-1MP_P0.50mm_Horizontal
JP1: Jumper_2x3_Open; SolderJumper-2x3_P1.3mm_Open_Pad1.0x1.5mm
R1, R2: 100; R_0402_1005Metric
R3, R4: 47k; R_0402_1005Metric
U1: CY8C20666A-24LQXI; QFN-48-1EP_6x6mm_P0.4mm_EP4.6x4.6mm

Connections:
/ADDR0: JP1.2 (C), R3.1, U1.23 (P1[2])
/ADDR1: JP1.5 (A), R4.1, U1.24 (P1[4])
/EVENT: J2.5, U1.25 (P1[6])
/I2C_SCL: J1.4, J2.4, R1.2
/I2C_SDA: J1.3, J2.3, R2.2
/SENSE1: J3.2, U1.27 (P3[0])
/SENSE2: J3.3, U1.28 (P3[2])
/SENSE3: J3.4, U1.29 (P3[4])
/SENSE4: J3.5, U1.30 (P3[6])
/SENSE5: J3.6, U1.31 (P4[0])
/SENSE6: J3.7, U1.32 (P4[2])
/SENSE7: J3.8, U1.33 (P2[0])
/SENSE8: J3.9, U1.34 (P2[2])
/SENSE9: J3.10, U1.35 (P2[4])
/SENSE10: J3.11, U1.36 (P2[6])
/SENSE11: J3.12, U1.37 (P0[0])
/SENSE12: J3.13, U1.38 (P0[2])
/SENSE13: J3.14, U1.39 (P0[4])
/SENSE14: J3.15, U1.40 (P0[6])
/SENSE15: J3.16, U1.44 (P0[7])
/SENSE16: J3.17, U1.45 (P0[5])
/SENSE17: J3.18, U1.46 ((INT)P0[3])
/SENSE18: J3.19, U1.2 (P2[7])
/SENSE19: J3.20, U1.3 (P2[5])
/SENSE20: J3.21, U1.4 (P2[3])
/SENSE21: J3.22, U1.5 (P2[1])
/SENSE22: J3.23, U1.6 (P4[3])
/SENSE23: J3.24, U1.7 (P4[1])
/SENSE24: J3.25, U1.8 (P3[7])
/SENSE25: J3.26, U1.9 (P3[5])
/SENSE26: J3.27, U1.10 (P3[3])
/SENSE27: J3.28, U1.11 (P3[1])
/SENSE28: J3.29, U1.12 ((SCL)P1[7])
/SENSE29: J3.30, U1.13 ((SDA)P1[5])
/SENSE30: J3.31, U1.16 (P1[3])
/XRES: J2.6, U1.26 (XRES)
GND: C1.1, C2.2, J1.1, J1.MP (MountPin), J2.1, J3.1, J3.32, J3.MP (MountPin), JP1.3 (B), JP1.6 (B), R3.2, R4.2, U1.18 (VSS), U1.47 (VSS2), U1.49 (Center_Pad)
unnamed: C2.1, U1.48 ((INT)P0[1])
unnamed: R1.1, U1.17 ((PR/SCL)P1[1])
unnamed: R2.1, U1.22 ((PR/SDA)P1[0])
VCC: C1.2, J1.2, J2.2, JP1.1 (A), JP1.4 (A), U1.21 (VDD), U1.41 (VDD2)

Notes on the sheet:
https://learn.bela.io/using-trill/all-about-i2c/
qwiic connector
I2C address setting solder jumpers
https://www.sparkfun.com/qwiic
THT Solderpads for wire connection

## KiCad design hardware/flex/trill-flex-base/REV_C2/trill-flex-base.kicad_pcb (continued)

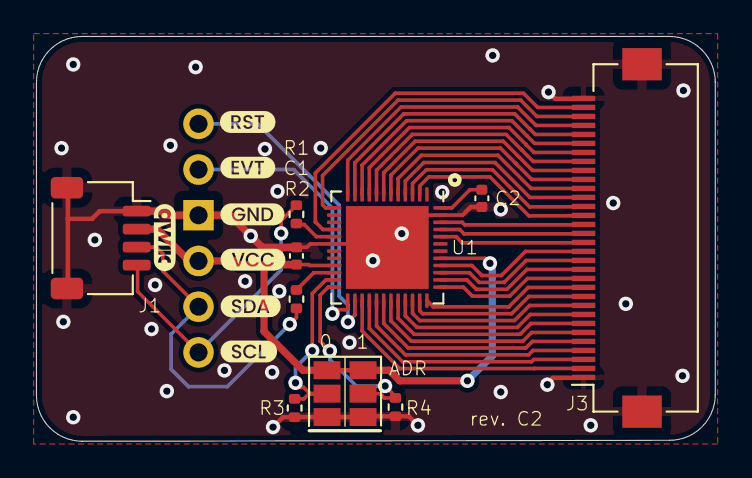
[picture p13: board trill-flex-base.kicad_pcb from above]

Board: 2 copper layers, 37.7 x 22.5 mm, 12 parts (1 on the bottom side), 41 nets.

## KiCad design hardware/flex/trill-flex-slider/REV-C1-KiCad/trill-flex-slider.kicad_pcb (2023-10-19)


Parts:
C1: trill-flex-conector; trill_flex_connector_long
CS1: TRILL_FLEX-30_CapSense; TRILL_FLEX_CapSense
G3: OpenSourceHardware_Logo

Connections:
unnamed: C1.1 (GND), C1.32 (GND), CS1.GND
unnamed: C1.2 (Sense1), CS1.1
unnamed: C1.3 (Sense2), CS1.2
unnamed: C1.4 (Sense3), CS1.3
unnamed: C1.5 (Sense4), CS1.4
unnamed: C1.6 (Sense5), CS1.5
unnamed: C1.7 (Sense6), CS1.6
unnamed: C1.8 (Sense7), CS1.7
unnamed: C1.9 (Sense8), CS1.8
unnamed: C1.10 (Sense9), CS1.9
unnamed: C1.11 (Sense10), CS1.10
unnamed: C1.12 (Sense11), CS1.11
unnamed: C1.13 (Sense12), CS1.12
unnamed: C1.14 (Sense13), CS1.13
unnamed: C1.15 (Sense14), CS1.14
unnamed: C1.16 (Sense15), CS1.15
unnamed: C1.17 (Sense16), CS1.16
unnamed: C1.18 (Sense17), CS1.17
unnamed: C1.19 (Sense18), CS1.18
unnamed: C1.20 (Sense19), CS1.19
unnamed: C1.21 (Sense20), CS1.20
unnamed: C1.22 (Sense21), CS1.21
unnamed: C1.23 (Sense22), CS1.22
unnamed: C1.24 (Sense23), CS1.23
unnamed: C1.25 (Sense24), CS1.24
unnamed: C1.26 (Sense25), CS1.25
unnamed: C1.27 (Sense26), CS1.26
unnamed: C1.28 (Sense27), CS1.27
unnamed: C1.29 (Sense28), CS1.28
unnamed: C1.30 (Sense29), CS1.29
unnamed: C1.31 (Sense30), CS1.30


Board: 2 copper layers, 149.6 x 21.6 mm, 3 parts (0 on the bottom side), 31 nets.

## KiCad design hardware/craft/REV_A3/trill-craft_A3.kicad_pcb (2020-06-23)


Board: 2 copper layers, 52.0 x 21.0 mm, 14 parts (0 on the bottom side), 41 nets.

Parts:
C1, C2: C-USC0603; C0603
G: Conn_01x01_Female; Circular_pad_smd
G#2: Conn_01x01_Female; Circular_pad_smd
IC1: CY8C206X6A; QFN48-LEADS
JP1: M06SILK_FEMALE_PTH; 1X06
JP3, JP4: Conn_01x15_Female; 1X15
Jumper0, Jumper1: Conn_01x03_Female; DOUBLE_SOLDER_JUMPER
R1, R2, R3, R4: R-EU_R0603; R0603

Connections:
/EVENT: IC1.2, JP1.2
/I2C_SCL: JP1.6, R1.2
/I2C_SDA: JP1.5, R2.2
/XRES: IC1.26, JP1.1
GND: C1.1, C2.2, G.1, G#2.1, IC1.18, IC1.47, IC1.EXP, JP1.3, Jumper0.3, Jumper1.3, R3.2, R4.2
unnamed: C2.1, IC1.48
unnamed: IC1.3, JP3.4
unnamed: IC1.4, JP3.5
unnamed: IC1.5, JP3.6
unnamed: IC1.6, JP3.7
unnamed: IC1.7, JP3.8
unnamed: IC1.8, JP3.9
unnamed: IC1.9, JP3.10
unnamed: IC1.10, JP3.11
unnamed: IC1.11, JP3.12
unnamed: IC1.12, JP3.13
unnamed: IC1.13, JP3.14
unnamed: IC1.16, JP3.15
unnamed: IC1.17, R1.1
unnamed: IC1.22, R2.1
unnamed: IC1.23, Jumper0.2, R3.1
unnamed: IC1.24, Jumper1.2, R4.1
unnamed: IC1.25, JP4.1
unnamed: IC1.27, JP4.2
unnamed: IC1.28, JP4.3
unnamed: IC1.29, JP4.4
unnamed: IC1.30, JP4.5
unnamed: IC1.31, JP4.6
unnamed: IC1.32, JP4.7
unnamed: IC1.33, JP4.8
unnamed: IC1.34, JP4.9
unnamed: IC1.35, JP4.10
unnamed: IC1.36, JP4.11
unnamed: IC1.37, JP4.12
unnamed: IC1.38, JP4.13
unnamed: IC1.39, JP4.14
unnamed: IC1.40, JP4.15
unnamed: IC1.44, JP3.1
unnamed: IC1.45, JP3.2
unnamed: IC1.46, JP3.3
VCC: C1.2, IC1.21, IC1.41, JP1.4, Jumper0.1, Jumper1.1

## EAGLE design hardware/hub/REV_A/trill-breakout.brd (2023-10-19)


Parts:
J1, J2, J3, J4, J5, J6, J7, J8, J9, J10: GROVE-SMT; JST-PH-4-SMT
J11, J12, J13, J14, J15, J16: M04LONGPADS; 1X04_LONGPADS
R1, R2: 2.2k; R0603

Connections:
GND: J1.4, J2.4, J3.4, J4.4, J5.4, J6.4, J7.4, J8.4, J9.4, J10.4, J11.4, J12.4, J13.4, J14.4, J15.4, J16.4
SCL: J1.1, J2.1, J3.1, J4.1, J5.1, J6.1, J7.1, J8.1, J9.1, J10.1, J11.1, J12.1, J13.1, J14.1, J15.1, J16.1, R2.1
SDA: J1.2, J2.2, J3.2, J4.2, J5.2, J6.2, J7.2, J8.2, J9.2, J10.2, J11.2, J12.2, J13.2, J14.2, J15.2, J16.2, R1.1
VCC: J1.3, J2.3, J3.3, J4.3, J5.3, J6.3, J7.3, J8.3, J9.3, J10.3, J11.3, J12.3, J13.3, J14.3, J15.3, J16.3, R1.2, R2.2


Board: 2 copper layers, 82.5 x 30.1 mm, 18 parts (0 on the bottom side), 4 nets.

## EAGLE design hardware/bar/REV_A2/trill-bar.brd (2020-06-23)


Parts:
C1, C2: C0402-SMALL
IC1: CY8C206X6A; QFN48-LEADS
J1: GROVE-SMT; JST-PH-4-SMT
PAD2-1Z1Z1O1K1, PAD2-2Z1Z1O1K1, PAD2-3Z1Z1O1K1, PAD2-4Z1Z1O1K1, PAD2-5Z1Z1O1K1, PAD2-6Z1Z1O1K1, PAD2-7Z1Z1O1K1, PAD2-8Z1Z1O1K1, PAD2-9Z1Z1O1K1, PAD2-9Z1Z1O1K2, PAD2-10Z1Z1O1K1, PAD2-11Z1Z1O1K1, PAD2-12Z1Z1O1K1, PAD2-13Z1Z1O1K1, PAD2-14Z1Z1O1K1, PAD2-15Z1Z1O1K1, PAD2-16Z1Z1O1K1, PAD2-17Z1Z1O1K1, PAD2-18Z1Z1O1K1, PAD2-19Z1Z1O1K1, PAD2-20Z1Z1O1K1, PAD2-21Z1Z1O1K1, PAD2-22Z1Z1O1K1, PAD2-23Z1Z1O1K1, PAD2-24Z1Z1O1K1, PAD2-25Z1Z1O1K1: SMD2; SMD1,27-2,54
R1, R2, R3, R4: R0402-SMALL; C0402-SMALL
U$7, U$8: SOLDER_JUMPER_3PAD
U$11, U$12: JST-SMT-EXTRAPAD

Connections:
ADDR0: IC1.23 (P1[2]), R3.P$2 (2), U$7.P$2
ADDR1: IC1.24 (P1[4]), R4.P$2 (2), U$8.P$2
EVENT: IC1.25 (P1[6]), U$11.P$1
GND: C1.P$1 (1), C2.P$2 (2), IC1.18 (VSS), IC1.47 (VSS2), IC1.EXP (VSS-PAD), J1.4, R3.P$1 (1), R4.P$1 (1), U$7.P$3, U$8.P$3
I2C_SCL: J1.1, R1.P$2 (2)
I2C_SDA: J1.2, R2.P$2 (2)
unnamed: C2.P$1 (1), IC1.48 ((INT)P0[1])
unnamed: IC1.17 ((PR/SCL)P1[1]), R1.P$1 (1)
unnamed: IC1.22 ((PR/SDA)P1[0]), R2.P$1 (1)
SENS1: IC1.27 (P3[0]), PAD2-9Z1Z1O1K2.1
SENS2: IC1.28 (P3[2]), PAD2-9Z1Z1O1K1.1
SENS3: IC1.29 (P3[4]), PAD2-8Z1Z1O1K1.1
SENS4: IC1.30 (P3[6]), PAD2-7Z1Z1O1K1.1
SENS5: IC1.31 (P4[0]), PAD2-6Z1Z1O1K1.1
SENS6: IC1.32 (P4[2]), PAD2-5Z1Z1O1K1.1
SENS7: IC1.33 (P2[0]), PAD2-10Z1Z1O1K1.1
SENS8: IC1.34 (P2[2]), PAD2-11Z1Z1O1K1.1
SENS9: IC1.35 (P2[4]), PAD2-12Z1Z1O1K1.1
SENS10: IC1.36 (P2[6]), PAD2-13Z1Z1O1K1.1
SENS11: IC1.16 (P1[3]), PAD2-14Z1Z1O1K1.1
SENS12: IC1.13 ((SDA)P1[5]), PAD2-15Z1Z1O1K1.1
SENS13: IC1.37 (P0[0]), PAD2-16Z1Z1O1K1.1
SENS14: IC1.38 (P0[2]), PAD2-17Z1Z1O1K1.1
SENS15: IC1.39 (P0[4]), PAD2-4Z1Z1O1K1.1
SENS16: IC1.40 (P0[6]), PAD2-3Z1Z1O1K1.1
SENS17: IC1.44 (P0[7]), PAD2-2Z1Z1O1K1.1
SENS18: IC1.45 (P0[5]), PAD2-1Z1Z1O1K1.1
SENS19: IC1.46 ((INT)P0[3]), PAD2-25Z1Z1O1K1.1
SENS20: IC1.6 (P4[3]), PAD2-24Z1Z1O1K1.1
SENS21: IC1.7 (P4[1]), PAD2-23Z1Z1O1K1.1
SENS22: IC1.8 (P3[7]), PAD2-18Z1Z1O1K1.1
SENS23: IC1.9 (P3[5]), PAD2-19Z1Z1O1K1.1
SENS24: IC1.10 (P3[3]), PAD2-20Z1Z1O1K1.1
SENS25: IC1.11 (P3[1]), PAD2-21Z1Z1O1K1.1
SENS26: IC1.12 ((SCL)P1[7]), PAD2-22Z1Z1O1K1.1
VCC: C1.P$2 (2), IC1.21 (VDD), IC1.41 (VDD2), J1.3, U$7.P$1, U$8.P$1
XRES: IC1.26 (XRES), U$12.P$1



Board: 4 copper layers, 101.6 x 21.6 mm, 38 parts (26 on the bottom side), 37 nets.

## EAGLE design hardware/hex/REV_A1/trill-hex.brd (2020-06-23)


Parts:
C1, C2: C0402-SMALL
IC1: CY8C206X6A; QFN48-LEADS
J1: GROVE-SMT; JST-PH-4-SMT
R1, R2, R3, R4: R0402-SMALL; C0402-SMALL
U$1, U$4, U$5, U$6, U$9, U$10, U$13, U$14, U$15, U$16, U$17, U$18, U$19, U$20, U$21, U$22, U$23, U$24, U$25, U$26, U$27, U$28, U$29, U$30, U$31, U$32, U$33, U$34, U$35, U$36: TP-SMALL; TESTPAD-SMALL
U$7, U$8: SOLDER_JUMPER_3PAD
U$11, U$12: JST-SMT-EXTRAPAD

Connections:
ADDR0: IC1.23 (P1[2]), R3.P$2 (2), U$7.P$2
ADDR1: IC1.24 (P1[4]), R4.P$2 (2), U$8.P$2
COL1: IC1.27 (P3[0]), U$4.P$1
COL2: IC1.28 (P3[2]), U$5.P$1
COL3: IC1.29 (P3[4]), U$1.P$1
COL4: IC1.30 (P3[6]), U$6.P$1
COL5: IC1.31 (P4[0]), U$9.P$1
COL6: IC1.32 (P4[2]), U$10.P$1
COL7: IC1.33 (P2[0]), U$13.P$1
COL8: IC1.13 ((SDA)P1[5]), U$35.P$1
COL9: IC1.44 (P0[7]), U$21.P$1
COL10: IC1.45 (P0[5]), U$22.P$1
COL11: IC1.3 (P2[5]), U$25.P$1
COL12: IC1.4 (P2[3]), U$26.P$1
COL13: IC1.5 (P2[1]), U$27.P$1
COL14: IC1.6 (P4[3]), U$28.P$1
EVENT: IC1.25 (P1[6]), U$11.P$1
GND: C1.P$1 (1), C2.P$2 (2), IC1.18 (VSS), IC1.47 (VSS2), IC1.EXP (VSS-PAD), J1.4, R3.P$1 (1), R4.P$1 (1), U$7.P$3, U$8.P$3
I2C_SCL: J1.1, R1.P$2 (2)
I2C_SDA: J1.2, R2.P$2 (2)
unnamed: C2.P$1 (1), IC1.48 ((INT)P0[1])
unnamed: IC1.17 ((PR/SCL)P1[1]), R1.P$1 (1)
unnamed: IC1.22 ((PR/SDA)P1[0]), R2.P$1 (1)
ROW1: IC1.16 (P1[3]), U$36.P$1
ROW2: IC1.12 ((SCL)P1[7]), U$34.P$1
ROW3: IC1.11 (P3[1]), U$33.P$1
ROW4: IC1.10 (P3[3]), U$32.P$1
ROW5: IC1.9 (P3[5]), U$31.P$1
ROW6: IC1.8 (P3[7]), U$30.P$1
ROW7: IC1.7 (P4[1]), U$29.P$1
ROW8: IC1.2 (P2[7]), U$24.P$1
ROW9: IC1.46 ((INT)P0[3]), U$23.P$1
ROW10: IC1.34 (P2[2]), U$14.P$1
ROW11: IC1.35 (P2[4]), U$15.P$1
ROW12: IC1.36 (P2[6]), U$16.P$1
ROW13: IC1.37 (P0[0]), U$17.P$1
ROW14: IC1.38 (P0[2]), U$18.P$1
ROW15: IC1.39 (P0[4]), U$19.P$1
ROW16: IC1.40 (P0[6]), U$20.P$1
VCC: C1.P$2 (2), IC1.21 (VDD), IC1.41 (VDD2), J1.3, U$7.P$1, U$8.P$1
XRES: IC1.26 (XRES), U$12.P$1



Board: 4 copper layers, 46.5 x 52.9 mm, 42 parts (30 on the bottom side), 41 nets.

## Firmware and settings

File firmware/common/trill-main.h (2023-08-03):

//----------------------------------------------------------------------------
// TRILL: Touch Sensing for Makers
// (c) 2020 Augmented Instruments Ltd
//
// These materials are licensed under the Creative Commons BY-SA-NC 4.0:
// Attribution, ShareAlike, Non-Commercial. For further information please
// contact info@bela.io.
//----------------------------------------------------------------------------

#include "trill.h"

// This file is supposed to be included after ID_DEVICE_TYPE has been defined, e.g.:
// #include "trill.h"
// #define ID_DEVICE_TYPE			ID_DEVICE_SQUARE
// #include "main.c"

#include <m8c.h>        // part specific constants and macros
#include "PSoCAPI.h"    // PSoC API definitions for all User Modules
#include "PSoCGPIOInt.h"

#define BUFFER_SWAP
#define TIMER16

#define BASE_I2C_ADDR_BAR		0x20
#define BASE_I2C_ADDR_SQUARE		0x28
#define BASE_I2C_ADDR_CRAFT		0x30
#define BASE_I2C_ADDR_RING		0x38
#define BASE_I2C_ADDR_HEX		0x40
#define BASE_I2C_ADDR_FLEX		0x48

#define ID_FIRMWARE_VERSION		0x02
#define ID_RESERVED			0x00

#if (ID_DEVICE_TYPE == ID_DEVICE_SQUARE) || (ID_DEVICE_TYPE == ID_DEVICE_HEX)
#define TWOD
#else
#define ONED
#endif


// This sets the range of I2C addresses for the sensors
// 7 addresses are possible, beginning at this address,
// depending on the settings of the 3 GPIO pins
const BYTE addresses[] = {
	0, // dummy
	BASE_I2C_ADDR_BAR,
	BASE_I2C_ADDR_SQUARE,
	BASE_I2C_ADDR_CRAFT,
	BASE_I2C_ADDR_RING,
	BASE_I2C_ADDR_HEX,
	BASE_I2C_ADDR_FLEX,
};
#define BASELINE_I2C_ADDRESS addresses[ID_DEVICE_TYPE]

// Pins for determining I2C address: P1[2], P1[4], P1[6]
#define I2C_ADDR_PORT_DATA		PRT1DR
#define I2C_ADDR_PORT_DIR0		PRT1DM0
#define I2C_ADDR_PORT_DIR1		PRT1DM1
#define I2C_ADDR_PIN0			(1 << 2)
#define I2C_ADDR_PIN1			(1 << 4)

// Pin for output EVENT signal
#if (ID_DEVICE_TYPE == ID_DEVICE_CRAFT)
#define EVENT_PORT_DATA			PRT2DR
#define EVENT_PORT_DIR0			PRT2DM0
#define EVENT_PORT_DIR1			PRT2DM1
#define EVENT_PIN			(1 << 7)
#else
#define EVENT_PORT_DATA			PRT1DR
#define EVENT_PORT_DIR0			PRT1DM0
#define EVENT_PORT_DIR1			PRT1DM1
#define EVENT_PIN			(1 << 6)
#endif

// Max number of touches to support
#ifdef TWOD
#define MAX_NUM_CENTROIDS	4
#else // TWOD
#define MAX_NUM_CENTROIDS	5
#endif // TWOD

// Size of the communication buffer, and byte where data begins
// within it (first part is reserved for commands)
#define COMM_BUFFER_SIZE_BYTES	64
#define COMM_DATA_OFFSET_BYTES	4
#define COMM_DATA_OFFSET_WORDS	2

#if (ID_DEVICE_TYPE == ID_DEVICE_BAR)
#define NUM_SENSORS 26				// How many sensors total: 26 on the Trill Bar
#else
#define NUM_SENSORS 30				// 30 sensors on all other devices
#endif
#define SLIDER_BITS 7				// Total slider range is 19*2^(SLIDER_BITS)
#define PACKED_CENTROID_LENGTH 8

#if (ID_DEVICE_TYPE == ID_DEVICE_SQUARE)
#define FIRST_SENSOR_V 15
#define LAST_SENSOR_V NUM_SENSORS
#define FIRST_SENSOR_H 0
#define LAST_SENSOR_H 15
#elif (ID_DEVICE_TYPE == ID_DEVICE_HEX)
#define FIRST_SENSOR_V 14
#define LAST_SENSOR_V NUM_SENSORS
#define FIRST_SENSOR_H 0
#define LAST_SENSOR_H 14
#elif (ID_DEVICE_TYPE == ID_DEVICE_RING)
#define FIRST_SENSOR_V 0
#define LAST_SENSOR_V (NUM_SENSORS-2)
#else
#define FIRST_SENSOR_V 0
#define LAST_SENSOR_V NUM_SENSORS
#endif

#ifdef TIMER16
// Timer. Here's how to compute the timer period:
//#define TIMER_CLOCK 32000 // Hz
//#define TIMER_DURATION 0.015 // seconds
//wTimerPeriod = (WORD)(TIMER_CLOCK * TIMER_DURATION); // Timer period (samples)
WORD wTimerPeriod = 0;
BYTE bTimerTicks;
#endif

#pragma interrupt_handler timer_ISR_Handler;
void timer_ISR_Handler(void);


enum {
	kCommandNone = 0,
	kCommandMode = 1,
	kCommandScanSettings = 2,
	kCommandPrescaler = 3,
	kCommandNoiseThreshold = 4,
	kCommandIdac = 5,
	kCommandBaselineUpdate = 6,
	kCommandMinimumSize = 7,
	kCommandAdjacentCentroidNoiseThreshold = 8,
	kCommandAutoScanInterval = 16,
	kCommandIdentify = 255
};

enum {
	kModeCentroid = 0,
	kModeRaw = 1,
	kModeBaseline = 2,
	kModeDiff = 3
};

#ifdef BUFFER_SWAP
#define NUM_BUFFERS 2
#else // BUFFER_SWAP
#define NUM_BUFFERS 1
#endif

BYTE bCurrentCommBuffer = 0;
WORD wCommBuffers[NUM_BUFFERS][COMM_BUFFER_SIZE_BYTES];	// Buffer for communication
WORD wVCentroid[MAX_NUM_CENTROIDS];			// Calculated (vertical) centroids
WORD wVCentroidSize[MAX_NUM_CENTROIDS];		// Size of (vertical) centroids
#ifdef TWOD
WORD wHCentroid[MAX_NUM_CENTROIDS];			// Calculated (horizontal) centroids
WORD wHCentroidSize[MAX_NUM_CENTROIDS];		// Size of (horizontal) centroids
#endif // TWOD

BYTE bMode = kModeCentroid;		// Mode in which to transmit data via I2C (set from host)
BYTE bCommand = kCommandNone;

WORD wMinimumCentroidSize = 0; 	// Size below which a centroid is ignored as noise
WORD wAdjacentCentroidNoiseThreshold = 400; // Trough between peaks needed to identify two centroids

extern BYTE CSD_bNoiseThreshold;
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

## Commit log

2020-06-23 Hardware and datasheet
    [trill-bar.brd, trill-bar.sch, trill-craft_A3.kicad_pcb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]
2020-07-02 Moved hw to subfolder
    [trill-bar.brd, trill-bar.sch, trill-craft_A3.kicad_pcb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]
2020-11-19 Added BOMs
    Closes https://github.com/BelaPlatform/Trill/issues/2
    [trill-bar-bom.xlsx, trill-craft-bom.xlsx, trill-hex-bom.xlsx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]
2021-03-03 Added Trill Flex files
    [trill-flex-bar.brd, trill-flex-bar.kicad_pcb, trill-flex-base-bom.xlsx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]
2022-10-21 KiCad Eagle import or Trill square, gitignore
    [trill-square-bom.xlsx, trill-square.brd, trill-square.kicad_sch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]
2023-02-09 Added FLEX to common headers
    [trill-main.h]
2023-10-19 added current source files for rev C series
    [trill-bar-bom.xlsx, trill-bar.brd, trill-bar.kicad_pcb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]
2023-10-26 added added trill craft as a symbol, footprint and 3dmodel. fixes #5
2025-01-31 adding all trill craft footprints
2025-01-31 adding REV3 of Craft design
    [trill-craft-castellated.csv, trill-craft-castellated.kicad_pcb, trill-craft-castellated.kicad_sch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]
2025-02-03 moving remaining craft footprint from general footprint library

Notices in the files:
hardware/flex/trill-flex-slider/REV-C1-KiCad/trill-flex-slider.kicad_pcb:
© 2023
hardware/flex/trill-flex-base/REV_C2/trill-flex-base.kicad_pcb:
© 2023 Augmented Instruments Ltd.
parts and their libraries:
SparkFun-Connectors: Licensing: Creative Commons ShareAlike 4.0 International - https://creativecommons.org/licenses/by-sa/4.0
